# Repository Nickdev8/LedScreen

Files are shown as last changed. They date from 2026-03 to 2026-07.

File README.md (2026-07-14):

<p>
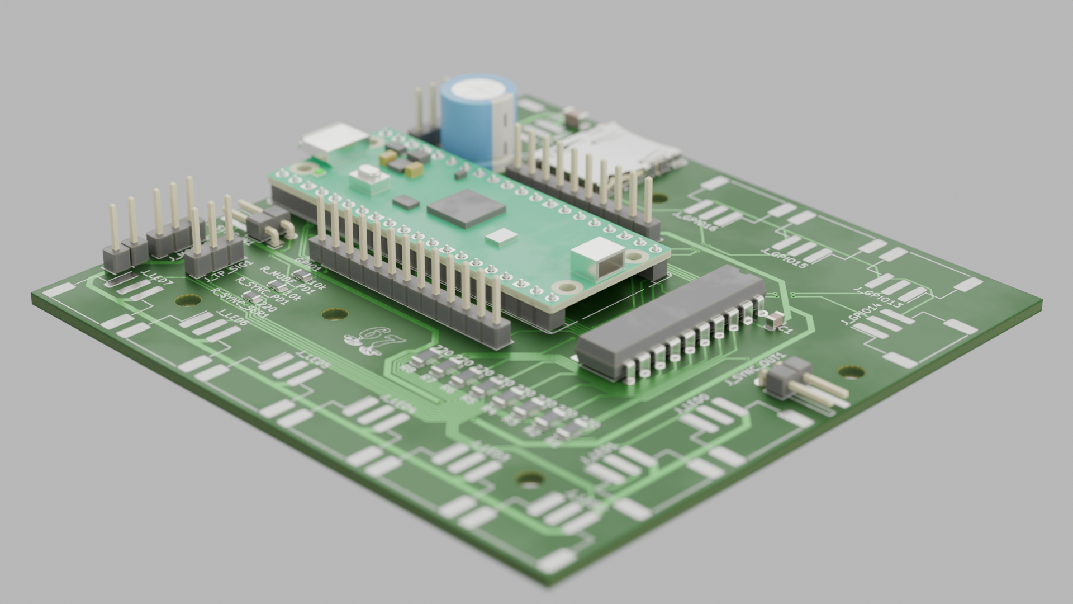
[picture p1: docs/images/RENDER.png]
  
  jlcpcb orders
</p>
# Led Control Board
Status: PCB, Firmware, Hardware and examples are Completly done!

With this board you can control multiple WS2812 LED lines with XLight sequences.
The main idea is that I wanted one board that could handle the panel data, SD card playback, and animation syncing between boards. That i all achieved with this pcb.

## Project Purpose
### Why I Built This
One of my close friends, Ruben, wanted to build a big LED panel project with me so we could display text, animations, and more.
After this board is fully working, I also want to use it in 2 daft punk helmets for Comic-Con 2026.

### BOM
- Raspberry Pi Pico
- 74HCT245
- 1000uF Cap
- 8x 220 ohm Resistor
- 100nF Cap (optionaly)
- 4.7uF Cap (optionaly)
- 2x 10k Res (optionaly for board Sync)

## How do you use it?
If you want to update the code on the MCU, I would really suggest reading [The firmware instuctions](docs/FIRMWARE_INSTUCTIONS.md).
If you want to update the animations on the display, read [the animation instuctions](docs/ANIMATIONS_INSTUCTIONS.md).

The basic idea is:
1. Flash the Pico with the firmware from `arduino_firmware/Main/`.
2. Put `.lsa` animation files in the SD card root.
3. Connect the LED panels and power them from an external regulated 5V PSU.
4. If needed, chain multiple boards together with the sync in/out headers.

## Firmware / Software
The Pico runs my own firmware in the [`arduino_firmware/`](arduino_firmware/) folder.
To Install make sure you have the `Earle Philhower Arduino-Pico core board` library

### SD Card Playback
- The Pico firmware reads root-level `.lsa` files from a FAT32 SD card.
- Files named `startup*.lsa` play once at boot in case-insensitive alphabetical order.
- Every other `.lsa` file then plays in case-insensitive alphabetical order, repeating the complete playlist forever.
- Prefix normal files with numbers such as `01_intro.lsa` and `02_logo.lsa` to control their order.
- Long filenames such as `startup_1.lsa` are supported.
- USB live streaming and GIF playback are not part of the active firmware.

## Project Files
- [`pcb/src/`](pcb/src/LedScreen.kicad_sch) - PCB sourse
- [`pcb/exports/LedScreen.pdf`](pcb/exports/LedScreen.pdf) - exported schematic PDF
- [`pcb/exports/gerber.zip`](pcb/exports/gerber.zip) - gerbers bundled for fabrication upload
- [`pcb/Gerber/`](pcb/Gerber/) - individual gerber outputs
- [`pcb/bom/ibom.html`](pcb/bom/ibom.html) - interactive BOM
- [`mechanical/case/`](mechanical/case/) - case and standoff print files
- [`xlights_project/`](xlights_project/) - xLights example project for driving the board
- [`scripts/fseq_to_lsa.py`](scripts/fseq_to_lsa.py) - convert xLights FSEQ files to `.lsa`

## Notes
I also included an xLights example for controlling this board.
xLights configuration depends on the final data path used between xLights and the Pico.

Start with a smaller amount of daisy-chained panels per output lane while validating signal integrity and power behavior.
Use an external 5V PSU sized for the actual panel count and brightness.

## Bill of Materials
Interactive BOM: [cdn.nickesselman.nl](https://cdn.nickesselman.nl/ledpanel/ibom.html)

## Project Images
<p>
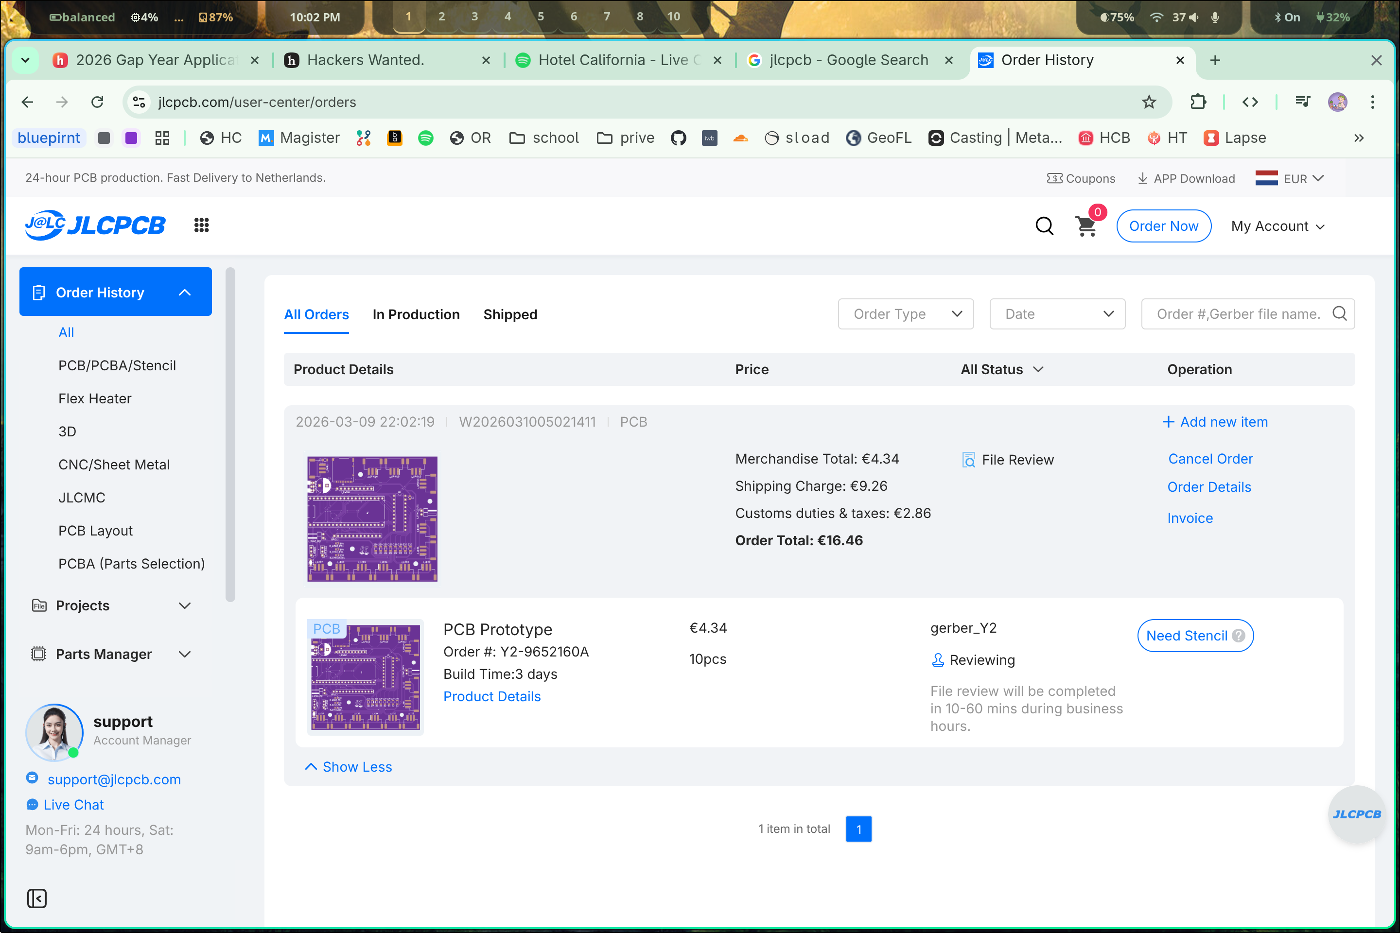
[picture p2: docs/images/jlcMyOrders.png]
jlcpcb orders
  
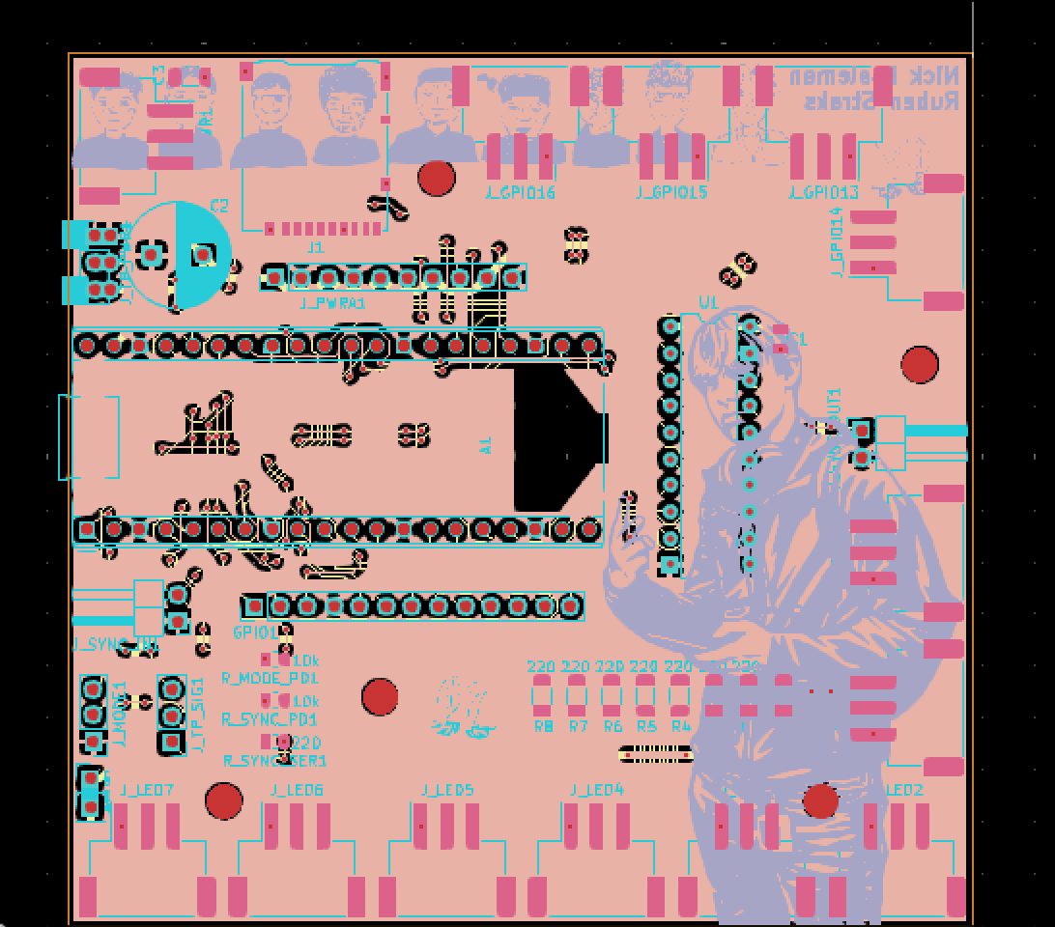
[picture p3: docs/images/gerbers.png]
gerbers
  
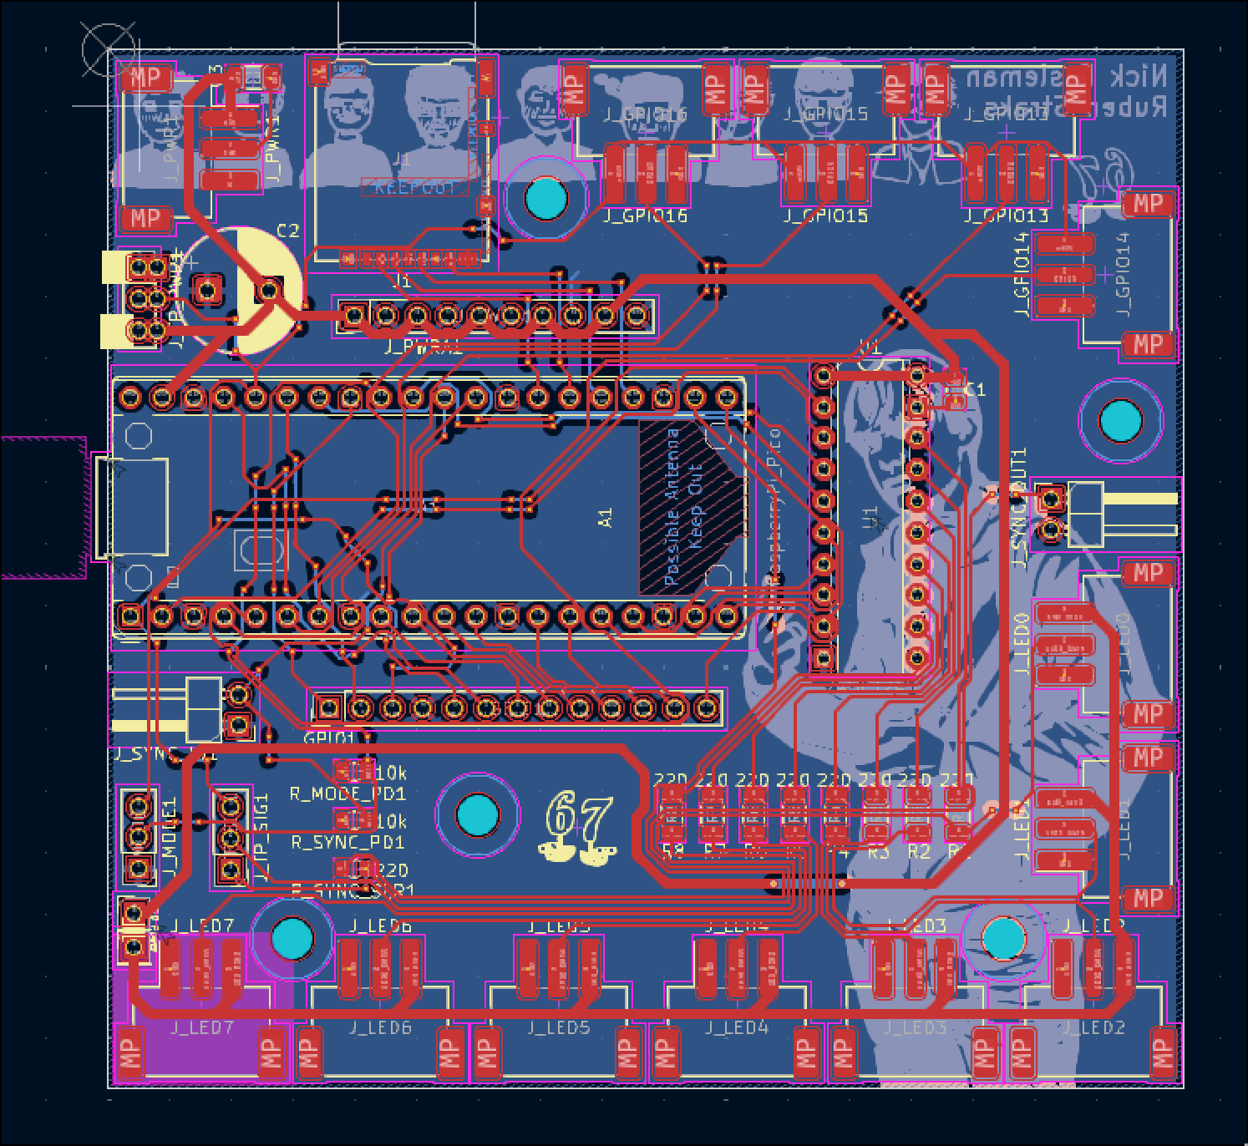
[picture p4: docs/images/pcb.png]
pcb
  
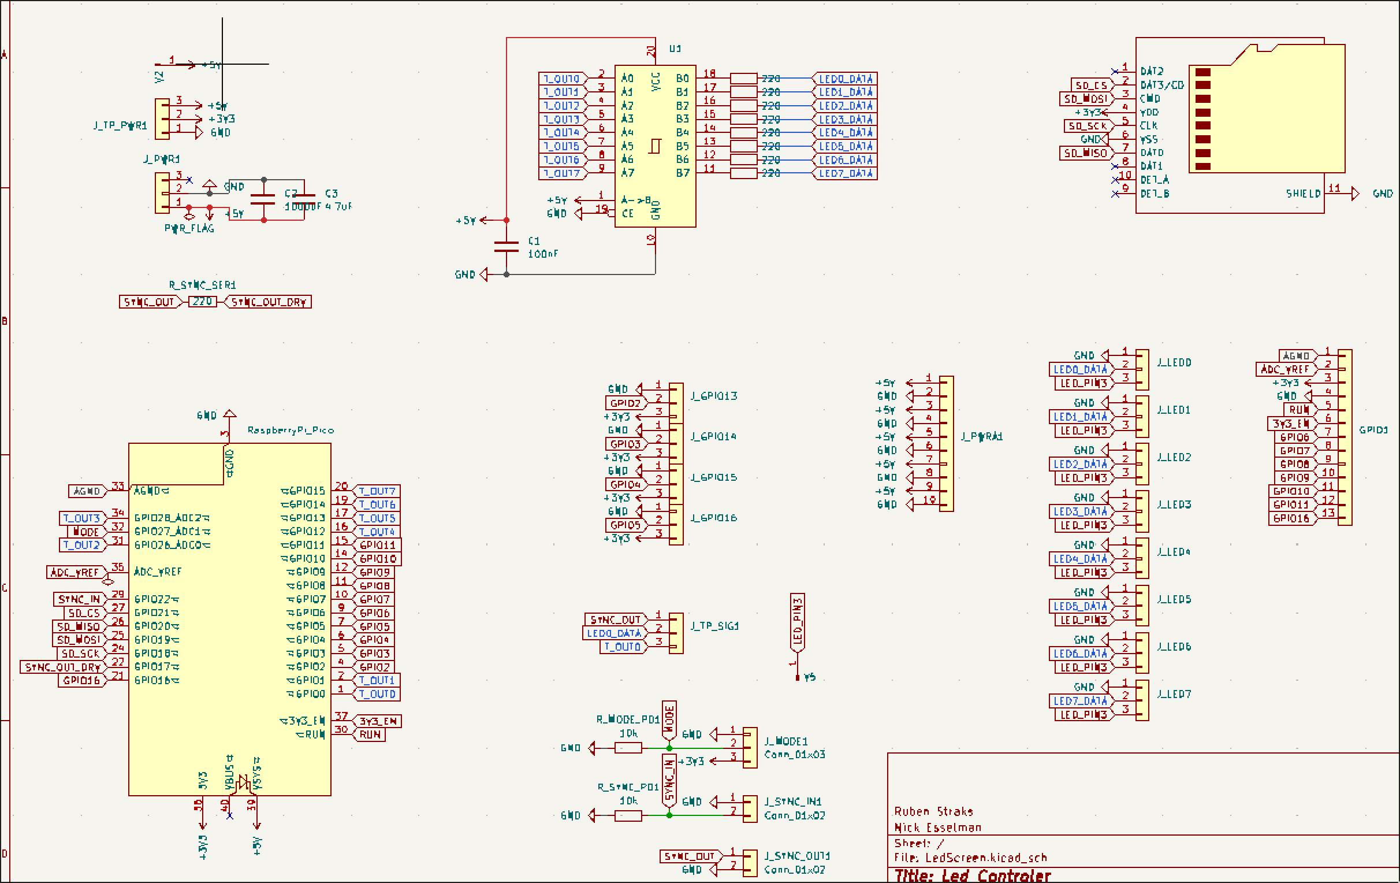
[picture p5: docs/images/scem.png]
schematic
  
</p>

## Build Photos
LED panels on the bench
Controller close-up

## License
- Hardware: CERN-OHL-S
- Firmware/Software: MIT License
- 
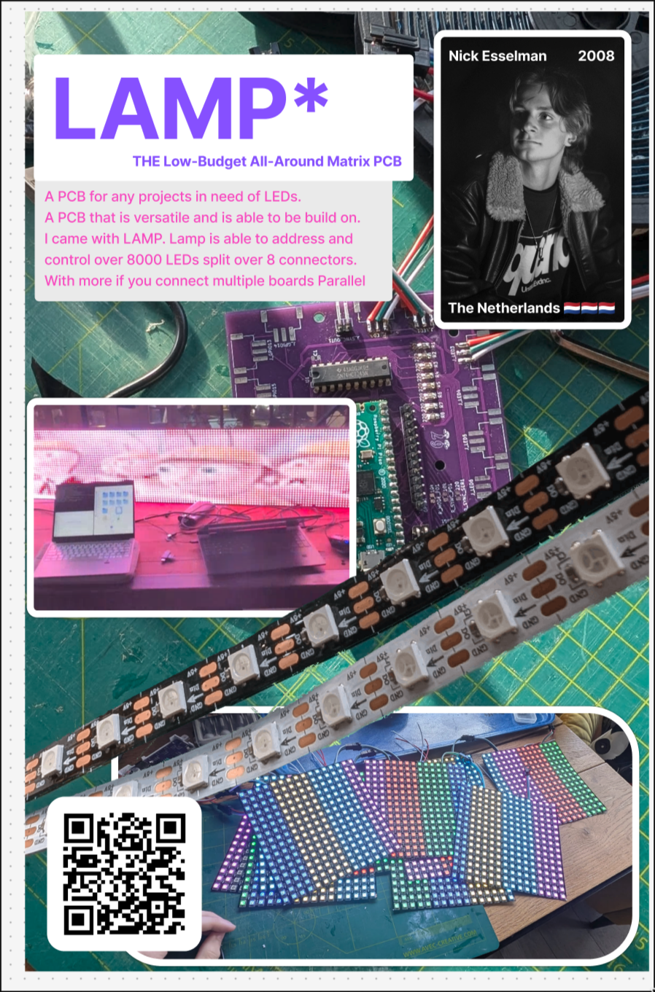
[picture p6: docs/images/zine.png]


# Daft Punk Helmets
I used this project for 2 Helmets, Guy manual (gold) & Thomas (Silver)
all 3d printed in about 200h of print time. and LED strips on the inside for the classic robot screen.
Models are in the repo and how i made this you can google and find on instrucables

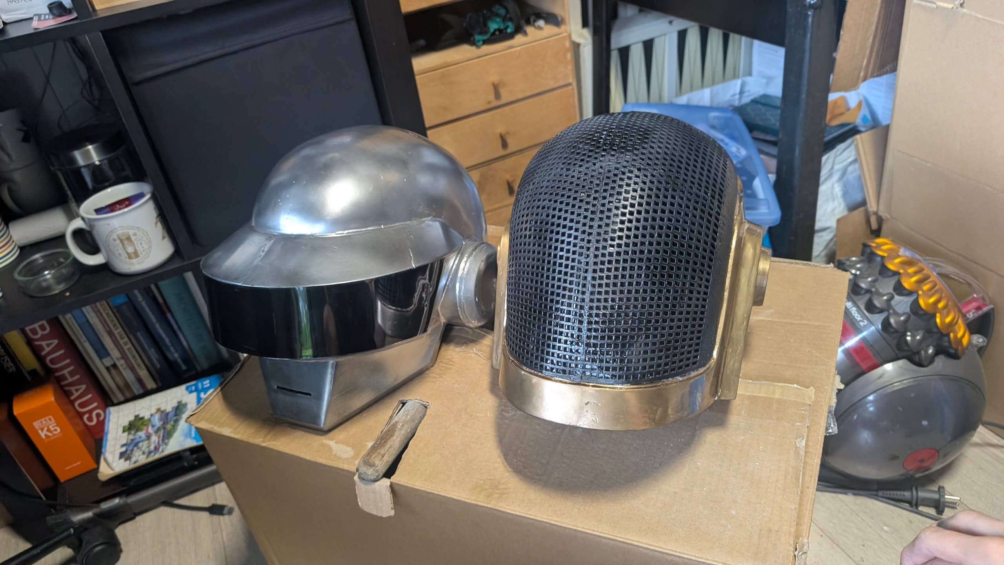
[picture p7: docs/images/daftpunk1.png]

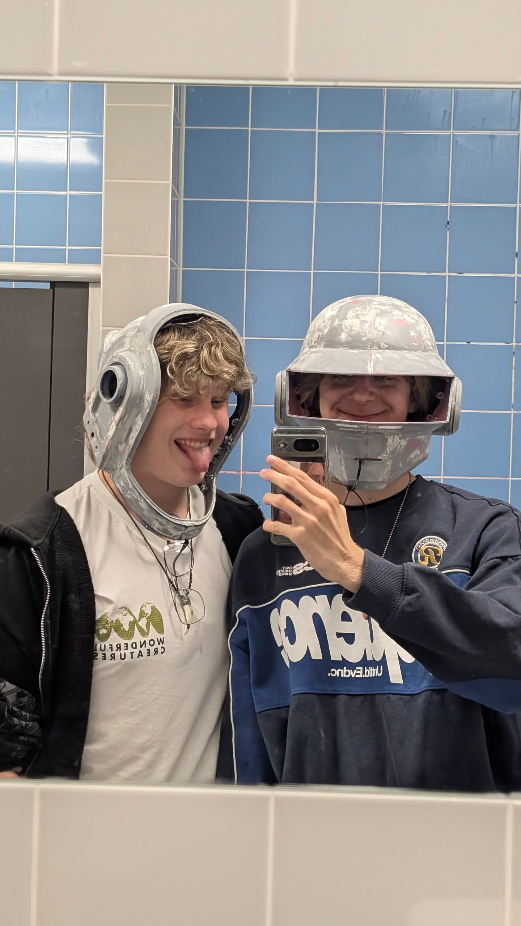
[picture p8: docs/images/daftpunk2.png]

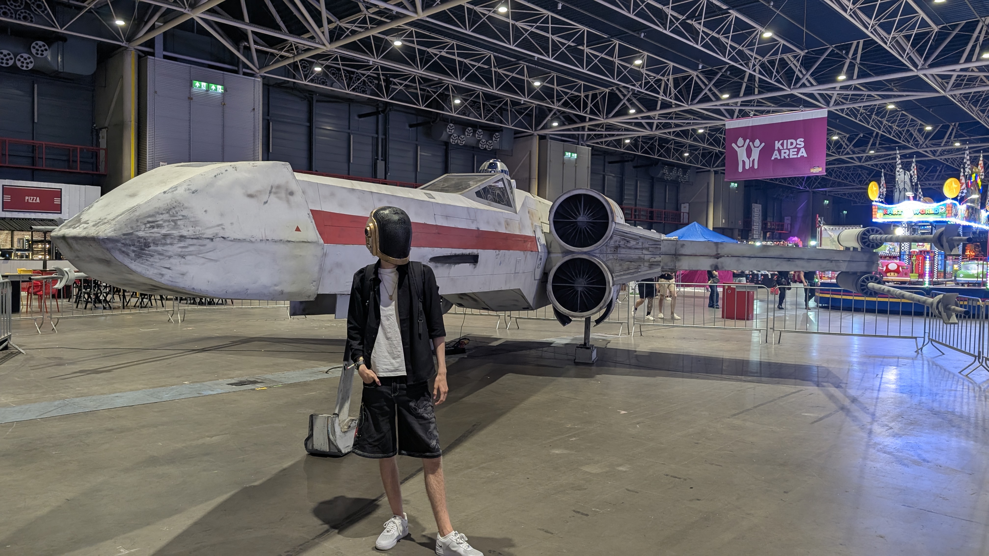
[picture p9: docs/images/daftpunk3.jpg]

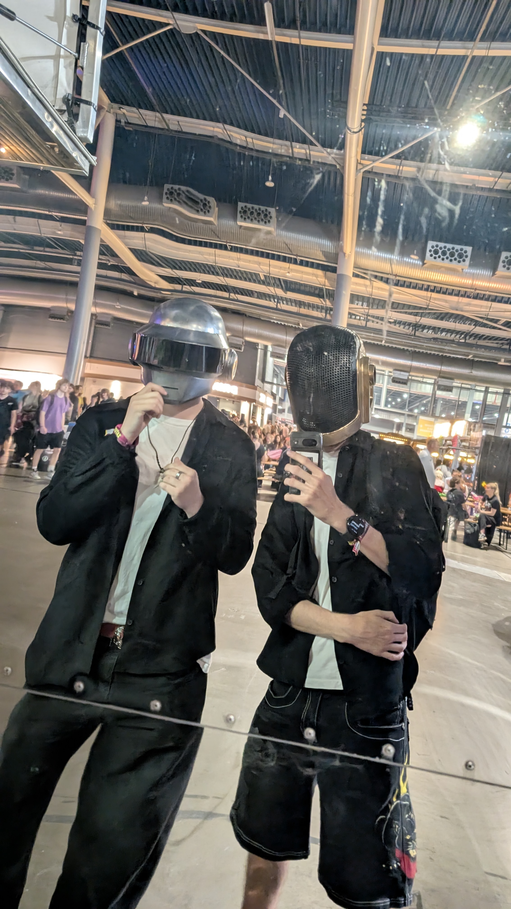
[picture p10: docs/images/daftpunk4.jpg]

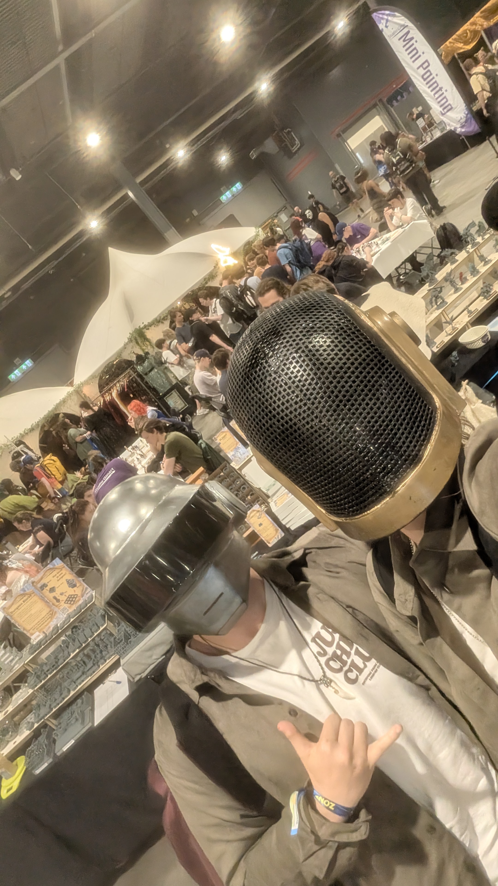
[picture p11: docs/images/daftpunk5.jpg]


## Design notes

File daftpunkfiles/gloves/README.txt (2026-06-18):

Daft Punk Gloves by KingHelps on Thingiverse: https://www.thingiverse.com/thing:177614

Summary:
Print yourself some Daft Punk gloves to go with the helmet!

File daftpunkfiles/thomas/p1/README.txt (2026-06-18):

Daft Punk Thomas 3D Printable Wearable Helmet by bendiger on Thingiverse: https://www.thingiverse.com/thing:338831

Summary:
If you like this design, buy me a beer :)http://www.thingiverse.com/bendiger/aboutUPDATE 09-17-16Thanks to all the hard work of Nathan720 (http://www.thingiverse.com/Nathan720), there is now an instructables post for how to build the helmets!http://www.instructables.com/id/Two-Daft-Punk-Helmets-in-One-Month/All the parts will be for the left side and just need to be mirrored to print the right.This design is for small 3D Printers with print beds 6x6in or bigger.All parts Zip tie or glue together.Support Material is a must unless you have a lot of faith in your printers capabilities and you can print extreme overhangs.About 120 hours of printing so far, and 2 reels of 3mm abs.It will be compatible with the AlexPlusLEDs matrix and side bar kits found here: http://alexplusleds.bigcartel.com/STL files orientated for printing on a 6x6 bed.Want the Guy Manuel Helmet? Here it is:http://www.thingiverse.com/thing:470882UPDATE 05-22-14: I've added the Visor to the list of files. Support material is required, I haven't made these with supports built-in yet, version 2 maybe.. More to follow soon.UPDATE 05-26-14: I've added the dome parts. I'm still working on the electronics mounts, those might be a while..UPDATE 09-01-14 I added the visor to the list of parts. This can be used to make molds from or bend plexiglass around and then cut to fit.UPDATE: 09-20-14Electronic mounts are finally done.Helmet design for V1 is done.Please tell me what changes you would like made. I want this to be the best version it can be.UPDATE: 10-10-14I've uploaded larger versions of all the parts after some feedback about the Guy Man helmet seeming larger. Turns out the Thomas was too small. The electronic mounts will be done soon. Little more work needed. The parts with v1.5 are the scaled versions. I've left the original parts.UPDATE 10-26-15Thought I should clarify some things since there seems to be some confusion. All of the parts that list v1.5 are a slightly larger version. the rest of the parts, 1.3, 1, and some without versioning, are the smaller helmet. There is an instructables that Fictive made recently on how to put the helmet together. http://goo.gl/cWfsDO

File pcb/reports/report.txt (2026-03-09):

Warning: Width correction constrained.  The width correction value must be in the range of [0,000001 mm; 0,199999 mm] for the current design rules.
Plotted to '/home/nick/Documents/projects/LedScreen/src/LedScreen-F_Cu.gtl'.
Plotted to '/home/nick/Documents/projects/LedScreen/src/LedScreen-B_Cu.gbl'.
Plotted to '/home/nick/Documents/projects/LedScreen/src/LedScreen-F_Silkscreen.gto'.
Plotted to '/home/nick/Documents/projects/LedScreen/src/LedScreen-B_Silkscreen.gbo'.
Plotted to '/home/nick/Documents/projects/LedScreen/src/LedScreen-F_Mask.gts'.
Plotted to '/home/nick/Documents/projects/LedScreen/src/LedScreen-B_Mask.gbs'.
Plotted to '/home/nick/Documents/projects/LedScreen/src/LedScreen-Edge_Cuts.gm1'.
Created Gerber job file '/home/nick/Documents/projects/LedScreen/src/LedScreen-job.gbrjob'.
Info: Done.
Plotted to '/home/nick/Documents/projects/LedScreen/src/geibers/LedScreen-F_Cu.gtl'.
Plotted to '/home/nick/Documents/projects/LedScreen/src/geibers/LedScreen-B_Cu.gbl'.
Plotted to '/home/nick/Documents/projects/LedScreen/src/geibers/LedScreen-F_Silkscreen.gto'.
Plotted to '/home/nick/Documents/projects/LedScreen/src/geibers/LedScreen-B_Silkscreen.gbo'.
Plotted to '/home/nick/Documents/projects/LedScreen/src/geibers/LedScreen-F_Mask.gts'.
Plotted to '/home/nick/Documents/projects/LedScreen/src/geibers/LedScreen-B_Mask.gbs'.
Plotted to '/home/nick/Documents/projects/LedScreen/src/geibers/LedScreen-Edge_Cuts.gm1'.
Created Gerber job file '/home/nick/Documents/projects/LedScreen/src/geibers/LedScreen-job.gbrjob'.
Info: Done.
Info: Done.
Info: Done.

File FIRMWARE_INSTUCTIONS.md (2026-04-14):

Things to note:
Ill first explain updating the firmware via the sd card. then via BOOTSEL. then via the andriod ide.

Putting new code on the board is not requered to update the LED animations.

To update LED aniamtions Please read [The animation Instuctions](ANIMATIONS_INSTUCTIONS.md)

The sd card reads for a file named [firmware.uf2](example_firmware.uf2). You can build this file from the adruino ide or find the latest in the [Repo's Releases page](https://github.com/Nickdev8/LedScreen/releases)

The other way is to hold down the BOOTSEL button while pluggin the usb of the pico into a laptop. and you should see a new drive apear. put the .uf2 file in there and next time you plug it in without holding the BOOTSEL button. it should load the new code.

The last option is to plug the Pico in with BOOTSEL pressed and uploading the sketch directly from the Adruino IDE. you would need to have the right libraries and board installed for this. linked here:

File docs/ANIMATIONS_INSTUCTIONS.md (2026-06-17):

# Animation files

Copy `.lsa` animation files into the root of a FAT32-formatted SD card.

On each boot:

1. Every file named `startup*.lsa` plays once in case-insensitive alphabetical order.
2. All other `.lsa` files play in case-insensitive alphabetical order.
3. After the final normal animation, the normal playlist starts again.

Examples:

- `startup.lsa`
- `startup_1.lsa`
- `01_intro.lsa`
- `02_logo.lsa`

Startup files are not included in the repeating playlist. If there are no startup files, normal playback begins immediately. If there are no normal files, the panel returns to its idle error indication after the startup files finish.

Generate `.lsa` files from xLights FSEQ exports with [`scripts/fseq_to_lsa.py`](../scripts/fseq_to_lsa.py), or convert videos with [`scripts/mp4_to_lsa.py`](../scripts/mp4_to_lsa.py). The xLights project is in [`xlights_project/`](../xlights_project/).

The active firmware reads animations only from the SD card. USB live preview and GIF playback are not supported.

To change the board size, update [`arduino_firmware/Main/Config.h`](../arduino_firmware/Main/Config.h) and rebuild the firmware.

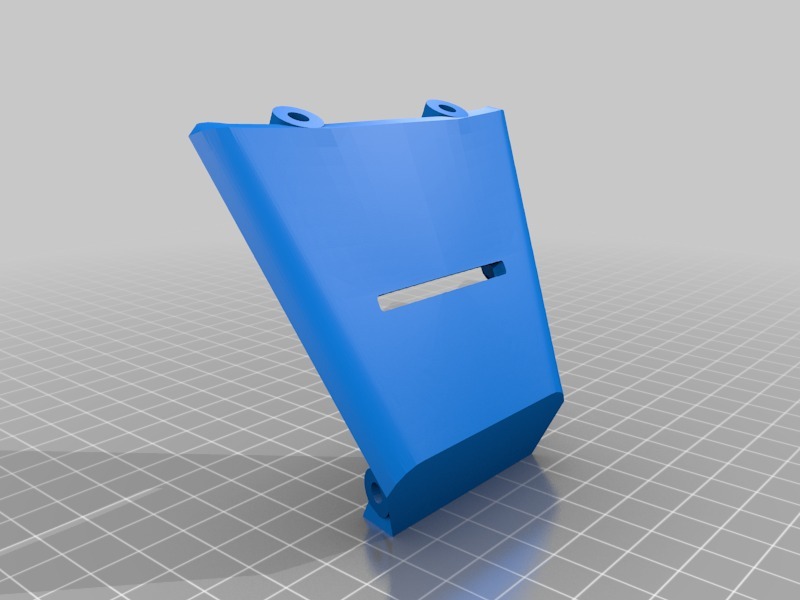
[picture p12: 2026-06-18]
daftpunkfiles/thomas/p1/images/Thomas_Helmet-Mouth.jpg

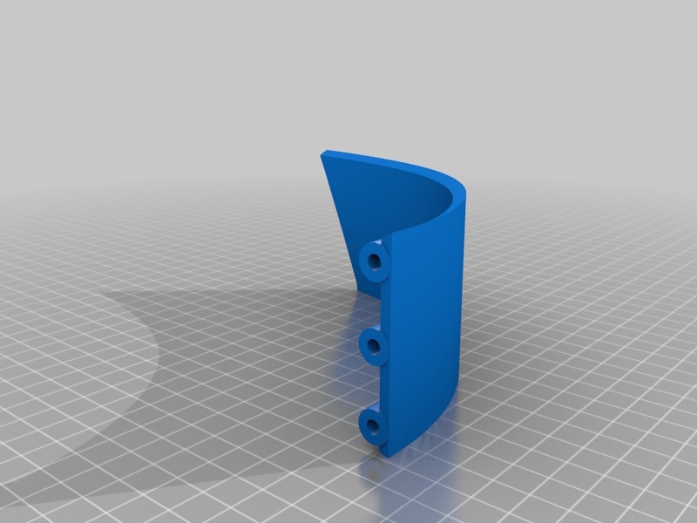
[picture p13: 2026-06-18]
daftpunkfiles/thomas/p1/images/Thomas_Helmet-VisorL.jpg

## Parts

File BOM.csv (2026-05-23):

Minimal Requred | Component name | Unit Price | pcb qty | Order qty | PART / LCSC | Distributor | Link / Notes | Total Price
TRUE | Raspberry Pi Pico | €3.5900 | 1 | 1 | RP2040 Pico | AliExpress | https://nl.aliexpress.com/item/1005009890247801.html?mp=1 | €3.59
TRUE | Micro SD card socket | €0.1590 | 1 | 10 | TF push-push 9pin | AliExpress | https://nl.aliexpress.com/item/1005001331379046.html?mp=1 | €1.59
FALSE | JST-SM 3-PIN Header Female | €0.0164 | 20 | 50 | PSB Connector | AliExpress | https://nl.aliexpress.com/item/1005009483624961.html?mp=1 | €0.82
FALSE | JST-SM 3-PIN Header Male | €0.0299 | 20 | 100 | PSB Connector | AliExpress | https://nl.aliexpress.com/item/1005005362711029.html?mp=1 | €2.99
FALSE | JST-XH LED connector cabel | €0.1750 | 20 | 40 | PSB Connector | AliExpress | https://nl.aliexpress.com/item/1005009696690444.html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 | €7.00
TRUE | SN74HCT245N | €0.7202 | 1 | 5 | C133640 | LCSC | https://www.lcsc.com/product-detail/C133640.html | €3.60
TRUE | 220Ω resistor 0805 | €0.0021 | 8 | 300 | C17557 | LCSC | https://www.lcsc.com/product-detail/C17557.html | €0.63
FALSE | 10kΩ resistor 0805 | €0.0020 | 2 | 200 | C84376 | LCSC | https://www.lcsc.com/product-detail/C84376.html | €0.40
FALSE | 100nF Capacitor 0805 | €0.0045 | 2 | 200 | C49678 | LCSC | https://www.lcsc.com/product-detail/C49678.html | €0.90
FALSE | 4.7uF Capacitor 1206 | €0.0339 | 1 | 50 | C51205 | LCSC | https://www.lcsc.com/product-detail/C51205.html | €1.70
TRUE | 1000uF Capacitor | €0.0843 | 1 | 10 | C51205 | LCSC | https://www.lcsc.com/product-detail/C72470.html | €0.84
FALSE | Pin header for Pico and Sync pins | €0.1273 | 5 | 15 | 2×20 pin header | LCSC | https://www.lcsc.com/product-detail/C2337.html | €1.91
FALSE |  |  |  |  |  |  |  | €0.00
FALSE | WS2812B 16×16 LED panel | €4.0900 | 25 | 25 | WS2812B 16×16 LED panel | Alibaba | https://dutch.alibaba.com/product-detail/WS2812B-RGB-Flexible-16x16-8x32-256Leds-1601298120275.html | €102.25
FALSE | WS2812B 5050 RGBIC LED-strip | €5.3900 | 3 | 3 | 5M 60 IP30 | AliExpress | https://nl.aliexpress.com/item/1005009321343937.html?mp=1 | €16.17
TRUE | 5V 30A PSU | €19.9900 | 2 | 2 | 5V 30A PSU | Amazon | https://www.amazon.nl/-/en/Adapter-Universal-Transformer-Computer-Surveillance/dp/B07PRY73TN | €39.98
FALSE |  |  |  |  |  | AliExpress |  | €0.00
FALSE | 16AWG power wire | €8.9900 | 5–10m | 1 | Routing to Panels | AliExpress | https://nl.aliexpress.com/item/1005008563402600.html?curPageLogUid=UtoHJnuT4ywC | €8.99

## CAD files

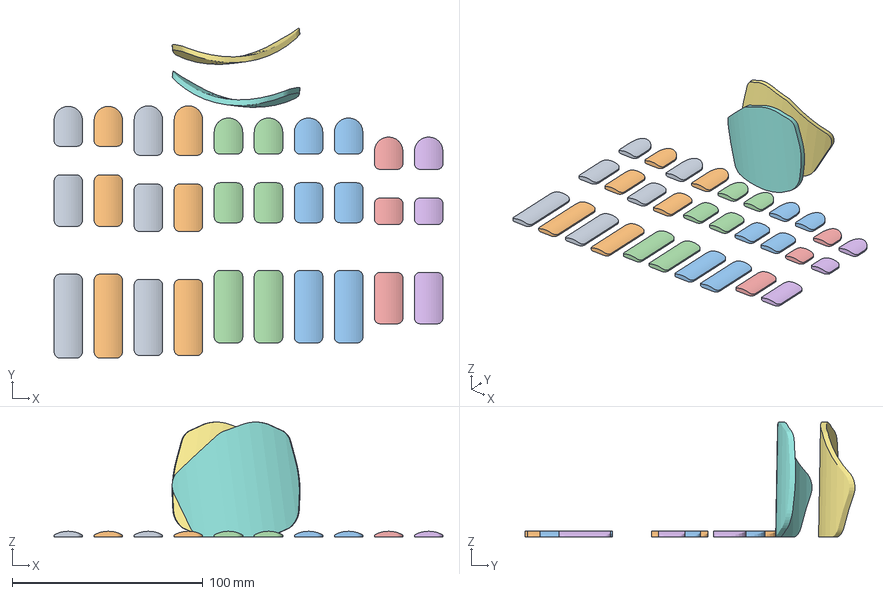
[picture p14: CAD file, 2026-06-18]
daftpunkfiles/gloves/complete1pair.3mf
204.0 x 173.1 x 60.2 mm
Thumb.stl
Ring.stl
Pinky.stl
Palm_mirrored.stl
Palm.stl
Middle.stl
Index.stl

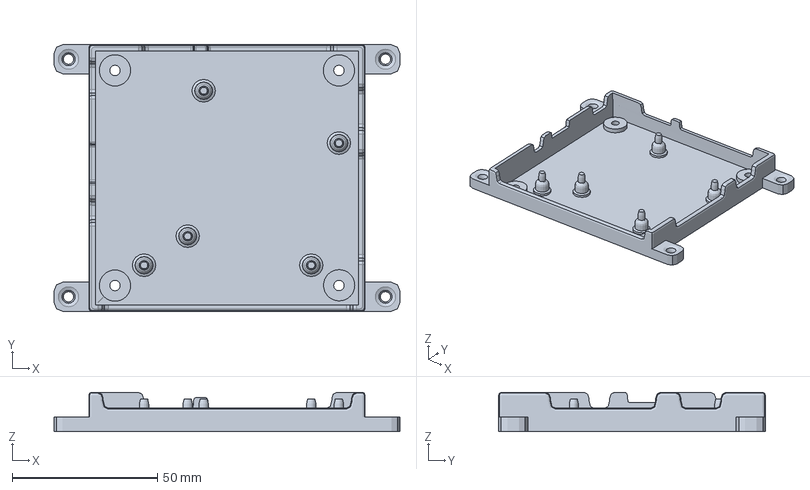
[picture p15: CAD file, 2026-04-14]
mechanical/case/casefull.3mf
119.0 x 91.7 x 13.5 mm

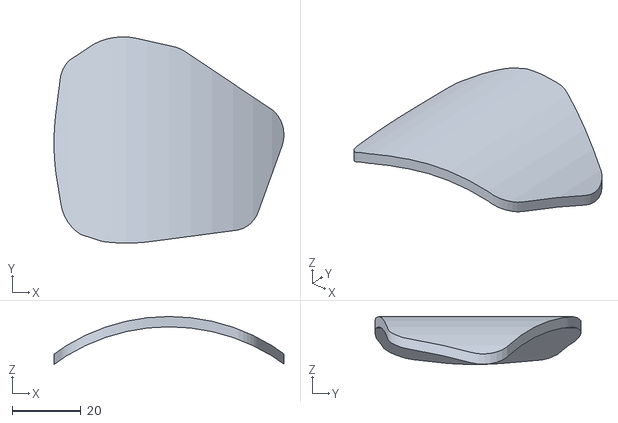
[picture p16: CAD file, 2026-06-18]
daftpunkfiles/gloves/files/Palm_mirrored.stl
66.9 x 60.0 x 14.0

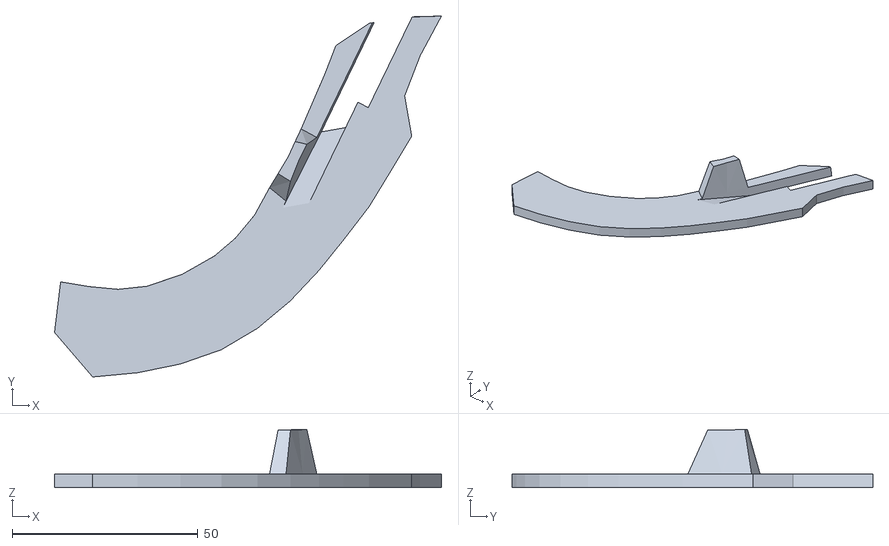
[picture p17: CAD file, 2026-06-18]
daftpunkfiles/guy manual/files/ChinLightMount-v1.5.stl
104.1 x 97.1 x 15.7

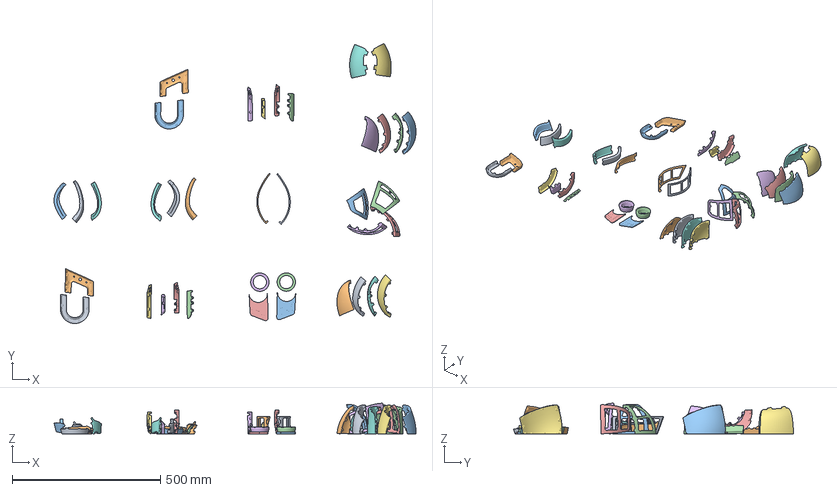
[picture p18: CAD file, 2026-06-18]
daftpunkfiles/guy manual/plates/leftside.3mf
1221.8 x 945.0 x 103.6 mm
SideTop-v1.5.stl
SideBottom-v1.5.stl
BackBar-v1.5.stl
SideShroud-BF-v1.5.stl
SideShroud-TB-v1.5.stl
SideShroud-BB-v1.5.stl
SideShroud-TF-v1.5.stl
TopBar-v1.5.stl
Chin-v1.5.stl
M-SideBottom-v1.5.stl
M-SideTop-v1.5.stl
M-SideShroud-BF-v1.5.stl
M-SideShroud-TB-v1.5.stl
M-SideShroud-TF-v1.5.stl
M-SideShroud-BB-v1.5.stl
M-TopBar-v1.5.stl
M-BackBar-v1.5.stl
M-Chin-v1.5.stl
VisorBottom-v1.5.stl x 2
VisorMidBottom-v1.5.stl x 2
VisorMidTop-v1.5.stl x 2
VisorTop-v1.5.stl x 2
visor1.stl
visor2.stl
visor3.stl
visor4.stl
BackWireHarness-V1.5.stl
M-BackWireHarness-V1.5.stl
thomasvisorl.stl
M-thomasvisorl.stl
CircuitPannel-v1.5.stl x 2
EarCupLR-Electronics-V1.5.stl x 2

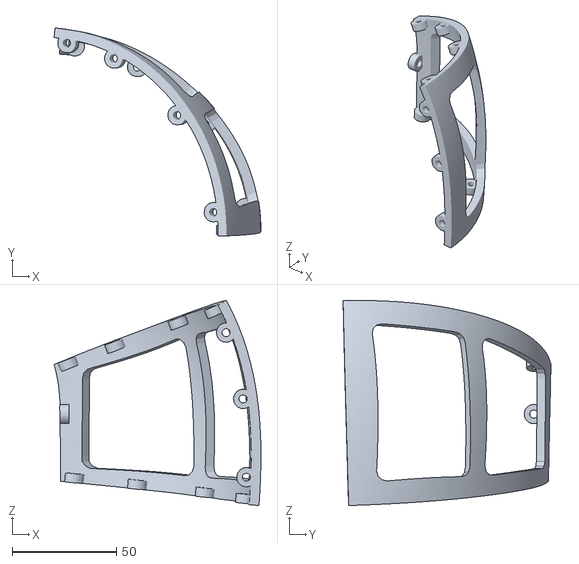
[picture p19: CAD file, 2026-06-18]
daftpunkfiles/guy manual/visor3.stl
99.2 x 99.6 x 98.3

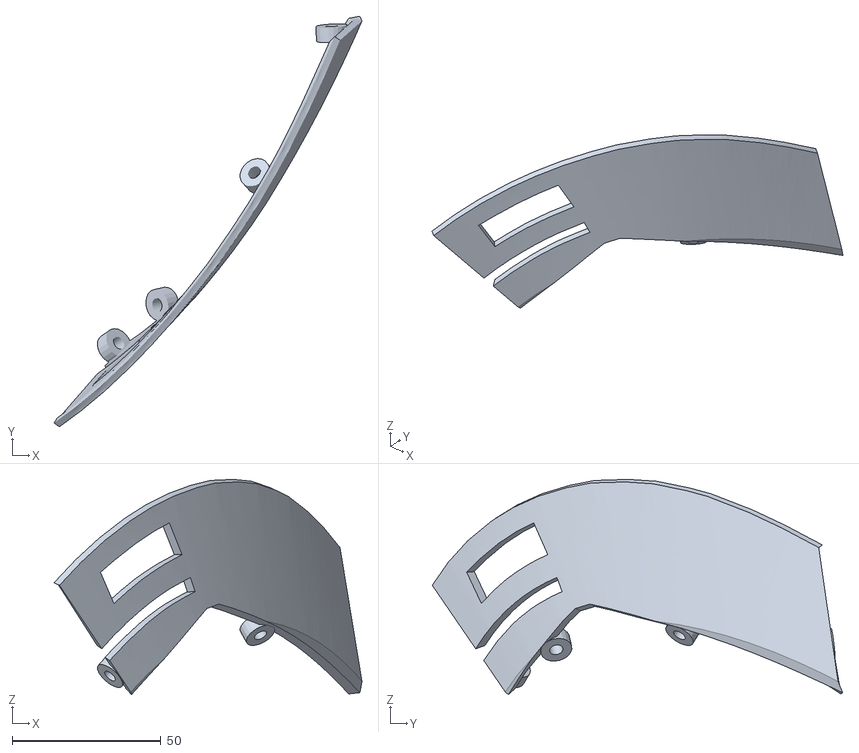
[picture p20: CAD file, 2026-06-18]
daftpunkfiles/thomas/p1/files/Thomas_Helmet-BottomVisor-Front-V1.5.stl
103.7 x 138.2 x 72.4

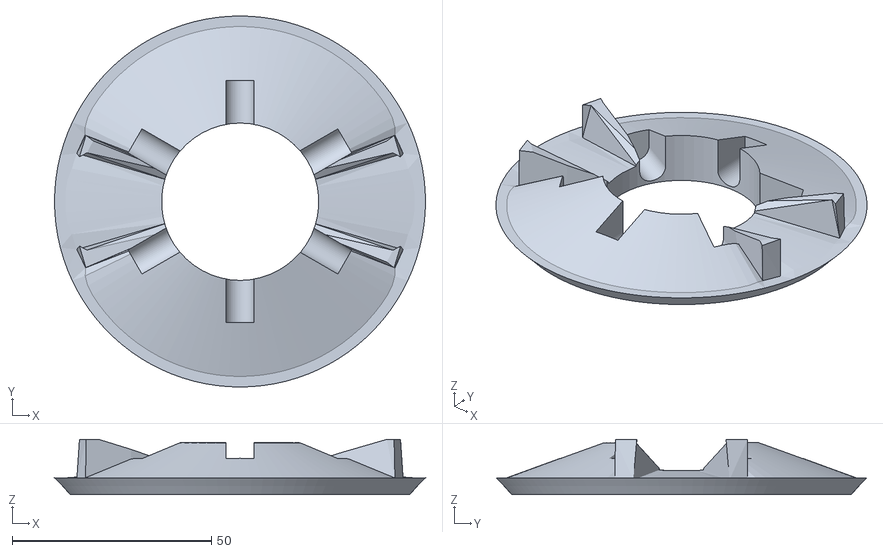
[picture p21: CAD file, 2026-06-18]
daftpunkfiles/thomas/p2/files/LightRing-v1.5.stl
93.2 x 93.2 x 13.9

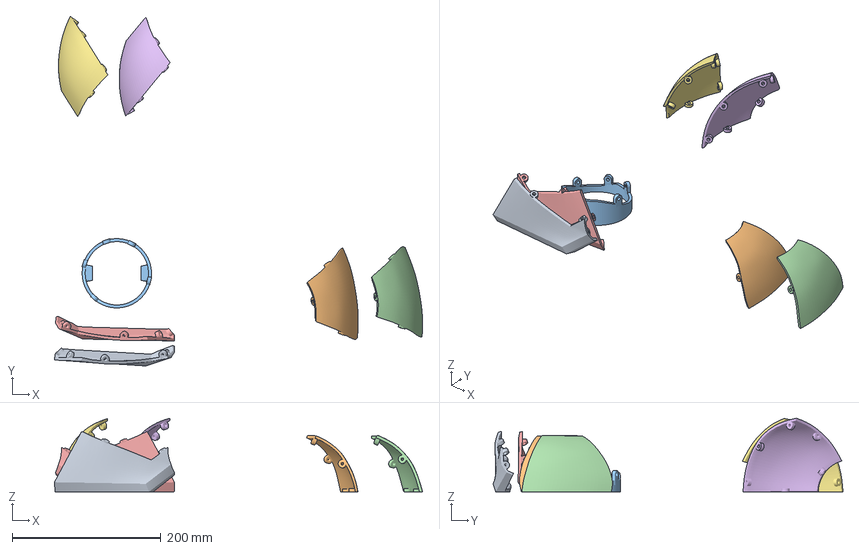
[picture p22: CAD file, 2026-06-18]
daftpunkfiles/thomas/thomastuhis.3mf
495.1 x 470.7 x 99.0 mm
Thomas_Helmet-Cheek-V1.5.stl
Thomas_Helmet-Dome-Side-V1.5.stl
M-Thomas_Helmet-EarMount-v1.5.stl
M-Thomas_Helmet-Dome-Side-V1.5.stl
M-Thomas_Helmet-Cheek-V1.5.stl
M-Thomas_Helmet-Dome-Back-Top-V1.5.stl
Thomas_Helmet-Dome-Back-Top-V1.5.stl

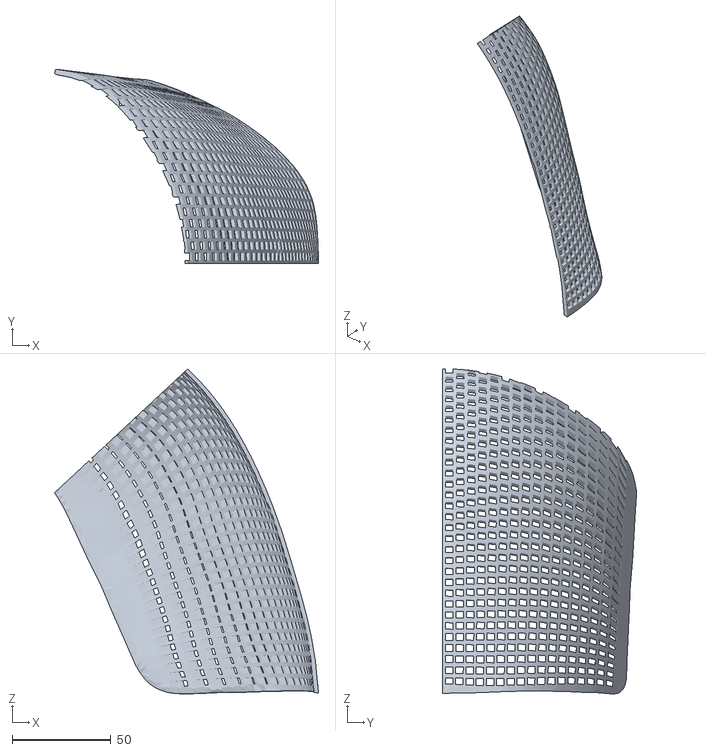
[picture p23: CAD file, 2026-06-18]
daftpunkfiles/visor2.stl
133.8 x 98.4 x 164.7

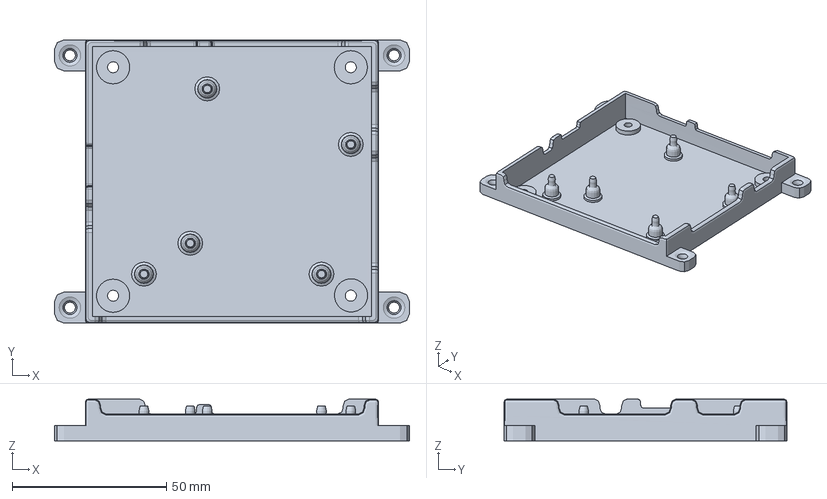
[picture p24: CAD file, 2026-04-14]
mechanical/case/StandOff.3mf
115.0 x 91.7 x 13.5 mm

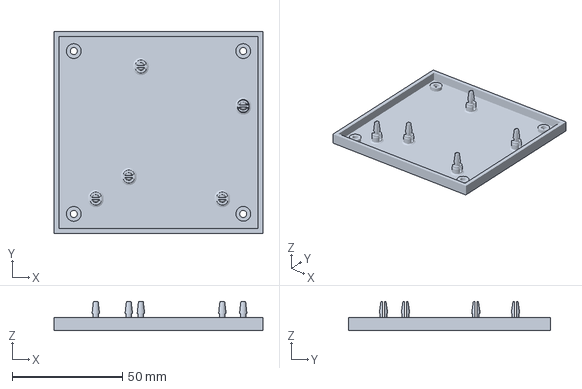
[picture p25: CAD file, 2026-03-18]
StandOff.3mf
95.0 x 91.7 x 13.2 mm

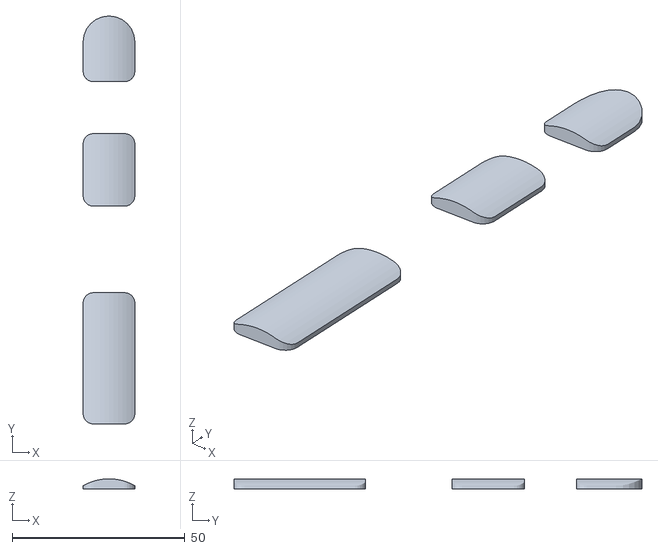
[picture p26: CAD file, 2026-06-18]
daftpunkfiles/gloves/files/Ring.stl
15.0 x 118.0 x 3.00

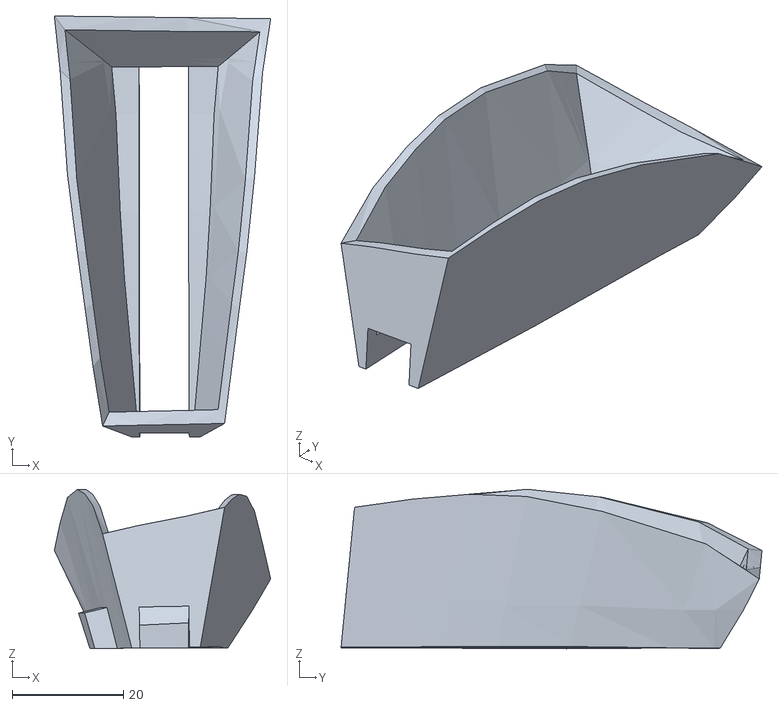
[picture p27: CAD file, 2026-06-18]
daftpunkfiles/guy manual/files/Fan-1_TopL-v1.5.stl
38.8 x 75.5 x 28.6

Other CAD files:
daftpunkfiles/guy manual/visor4.stl
daftpunkfiles/thomas/p1/files/Thomas_Helmet-Dome-Side.stl
daftpunkfiles/thomas/p2/files/Thomas_Helmet-Mouth-V1.5.stl
daftpunkfiles/thomas/thomas-1side.3mf
StandOff.stl
daftpunkfiles/gloves/files/Index.stl
daftpunkfiles/gloves/files/Middle.stl
daftpunkfiles/gloves/files/Palm.stl
daftpunkfiles/gloves/files/Pinky.stl
daftpunkfiles/gloves/files/Thumb.stl
daftpunkfiles/guy manual/files/BackBar-v1.5.stl
daftpunkfiles/guy manual/files/BackWireHarness-V1.5.stl
daftpunkfiles/guy manual/files/Chin-v1.5.stl
daftpunkfiles/guy manual/files/CircuitPannel-v1.5.stl
daftpunkfiles/guy manual/files/EarCupElectronicsBracket-V1.5.stl
daftpunkfiles/guy manual/files/EarCupLR-Electronics-V1.5.stl
daftpunkfiles/guy manual/files/Fan-2L-v1.5.stl
daftpunkfiles/guy manual/files/Fan-3L-v1.5.stl
daftpunkfiles/guy manual/files/Fan-4L-v1.5.stl
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

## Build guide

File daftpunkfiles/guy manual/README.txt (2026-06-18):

Daft Punk Guy Manuel 3D Printable Wearable Helmet by bendiger on Thingiverse: https://www.thingiverse.com/thing:470882

Summary:
If you like this design, buy me a beer :)http://www.thingiverse.com/bendiger/aboutUPDATE! 03-29-2025I know, sorry.... its been a while... I'm posting these updates for those that have asked. All version 2 files should be printed. All older files are out of date. I may delete them at some point. I've uploaded the 3MF, I can upload the STLs on request, but you will have to figure out the layout.This has been scaled to fit my head and the average head size of most people. Its also designed to fix on a Bambu Lab X1C. The 3MF file has everything laid out and oriented to the bed. I STRONGLY suggest supports. This is way less parts, and I have no plans on changing the assembly method. I have not printed this at all, so use at your own risk. I want to do more, but I already have both helmets. So unless people start donating, this is all I'm doing.UPDATE 09-17-16Thanks to all the hard work of Nathan720 (http://www.thingiverse.com/Nathan720), there is now an instructibles post for how to build the helmets!http://www.instructables.com/id/Two-Daft-Punk-Helmets-in-One-Month/It's what everyone has been waiting for!The Daft Punk Guy Manuel 3D Printable helmet for small printers!All the parts are for the left side and just need to be mirrored to print the right. Set the X scale to -1This design is for small 3D Printers with print beds 6x6in or bigger.All parts Zip tie or glue together.Support Material is a must for most parts. These are not optimized for supportless printing due to there shape.About 60 hours of printing so far, and 1 reels of 3mm abs.It will be compatible with the AlexPlusLEDs fans and chin lights which can be found here: http://alexplusleds.bigcartel.com/STL files are orientated for printing on a 6x6 bed.The visor mold that will soon be included can be used to make your own clear visor form for vacuum forming.Want the Thomas Bangalter Helmet? Here it is:http://www.thingiverse.com/thing:338831---UPDATES---06-27-15 Well, I should have updated this a while back. All the files are updated and scaled to match the Thomas Helmet. Hopefully they look good and work better size wise.10-16-14 I uploaded a quick Back Wire Harness for the wires on the back of the head. Its simple and will be updated to have groves to hold the wires in place.10-04-14 I've uploaded the visor mold and the support parts. All parts should be mirrored and glued together very well to handle vacuum forming. I suggest a good thick coat of epoxy or bondo on the inside of the mold to avoid cracking during forming. Please let me know if there are any problems with slicing, some of the parts were a rush job and didn't need to look pretty.Also, I have uploaded the ear cups and side panels. The ear cup is not ready for electronics, it was uploaded because of a request.

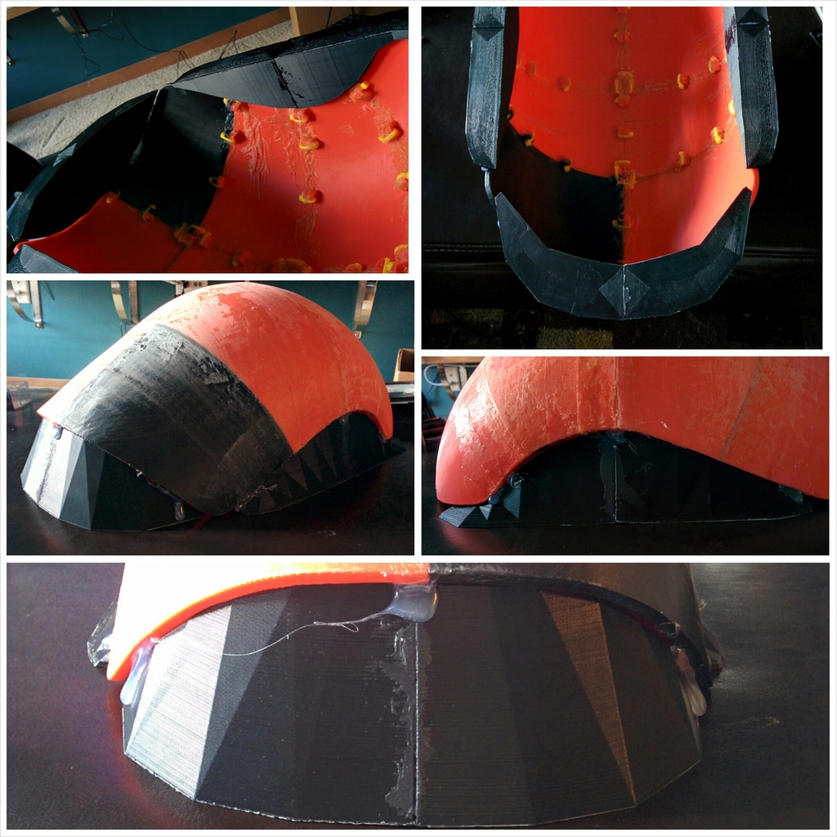
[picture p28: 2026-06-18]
daftpunkfiles/guy manual/images/September_27__2014_at_0333PM.jpg

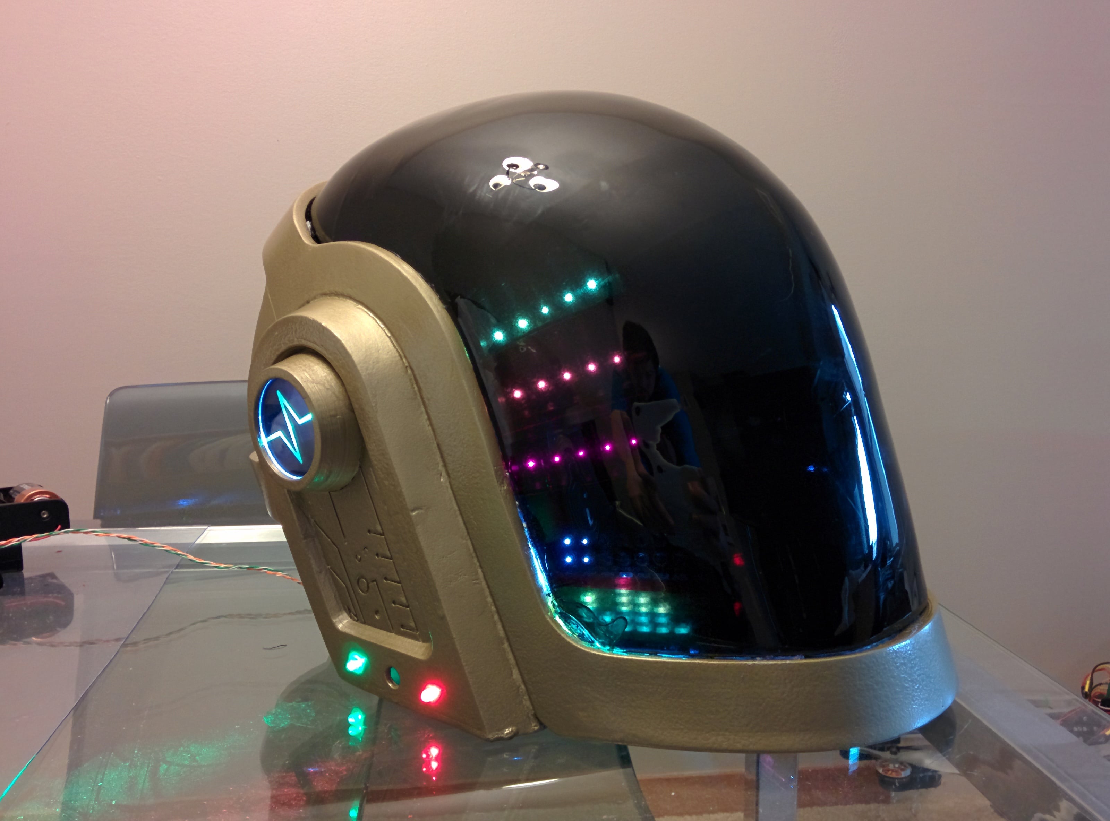
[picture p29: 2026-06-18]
daftpunkfiles/guy manual/images/November_02__2014_at_0413PM.jpeg

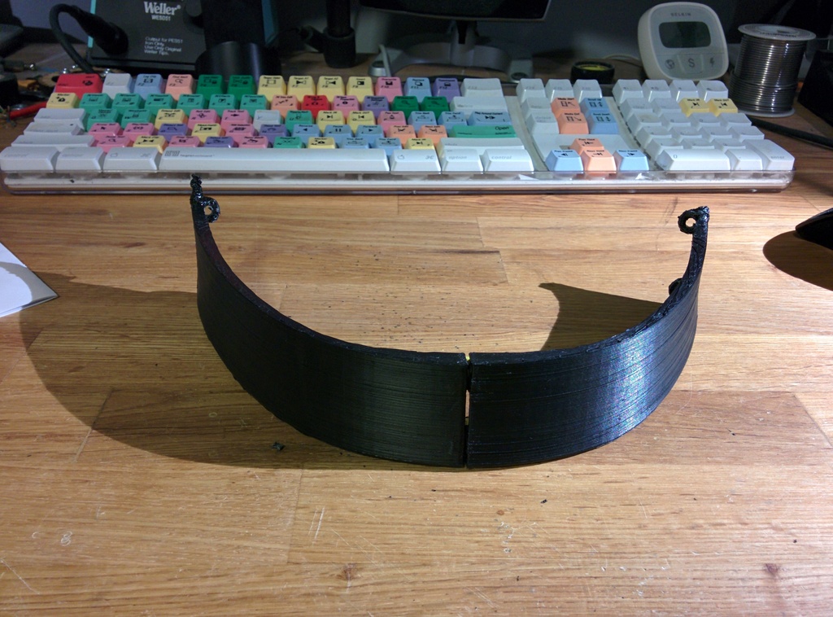
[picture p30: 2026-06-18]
daftpunkfiles/guy manual/images/August_03__2014_at_1111PM.jpg

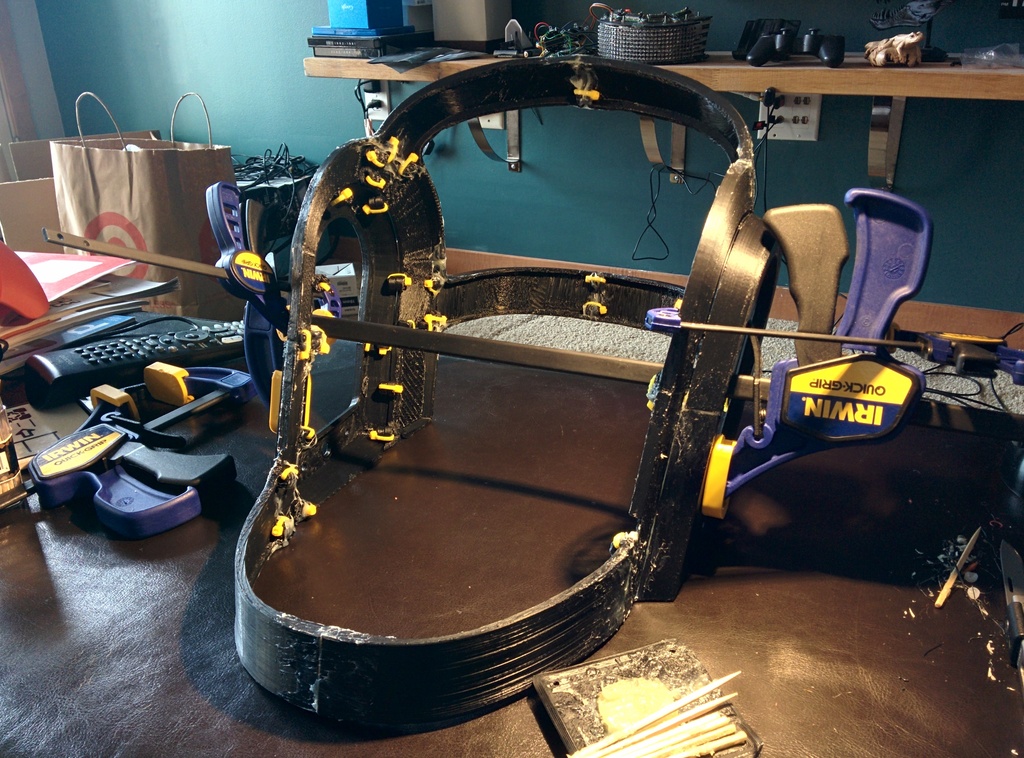
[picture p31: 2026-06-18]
daftpunkfiles/guy manual/images/September_08__2014_at_1208PM.jpg

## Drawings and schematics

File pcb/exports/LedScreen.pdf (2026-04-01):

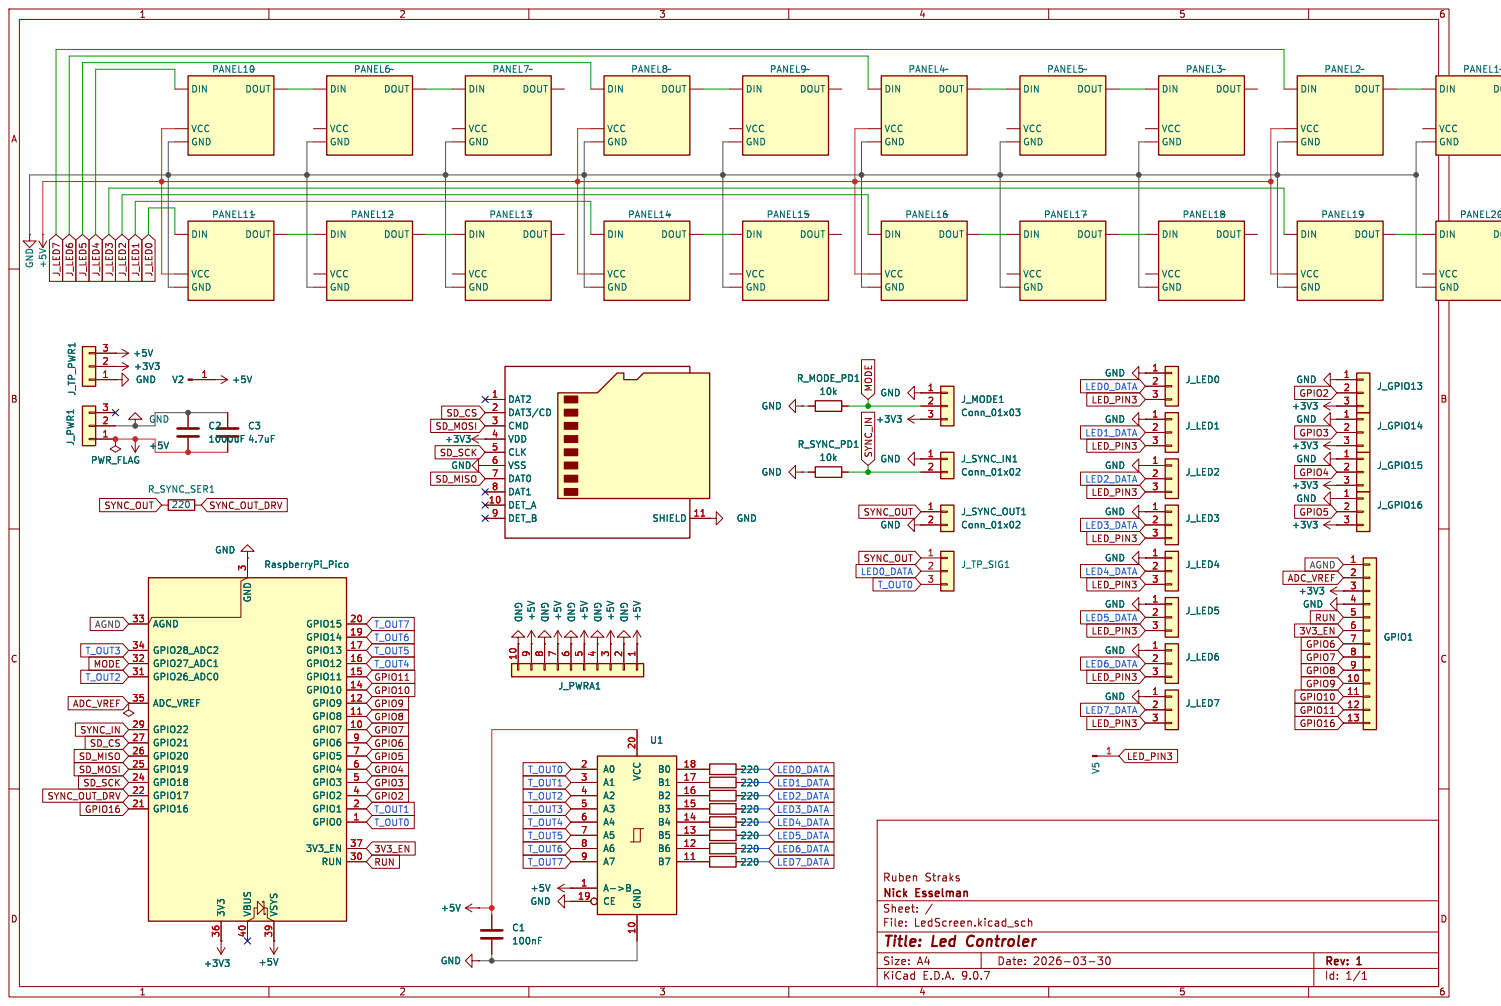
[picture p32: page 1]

3 3V3 36 GPIO16 21 GPIO17 22 GPIO18 24 GPIO19 25 GPIO20 26 GPIO21 27 GPIO22 29 ADC_VREF 35 GPIO26_ADC0 31 GPIO27_ADC1 32 GPIO28_ADC2 34 AGND 33 U1 A0 2 A1 3 A2 4 A3 5 A4 6 A5 7 A6 8 A7 9 A->B 1 CE 19 VCC 20 GND 10 B0 18 B1 17 B2 16 B3 15 B4 14 B5 13 B6 12 B7 11 +5V

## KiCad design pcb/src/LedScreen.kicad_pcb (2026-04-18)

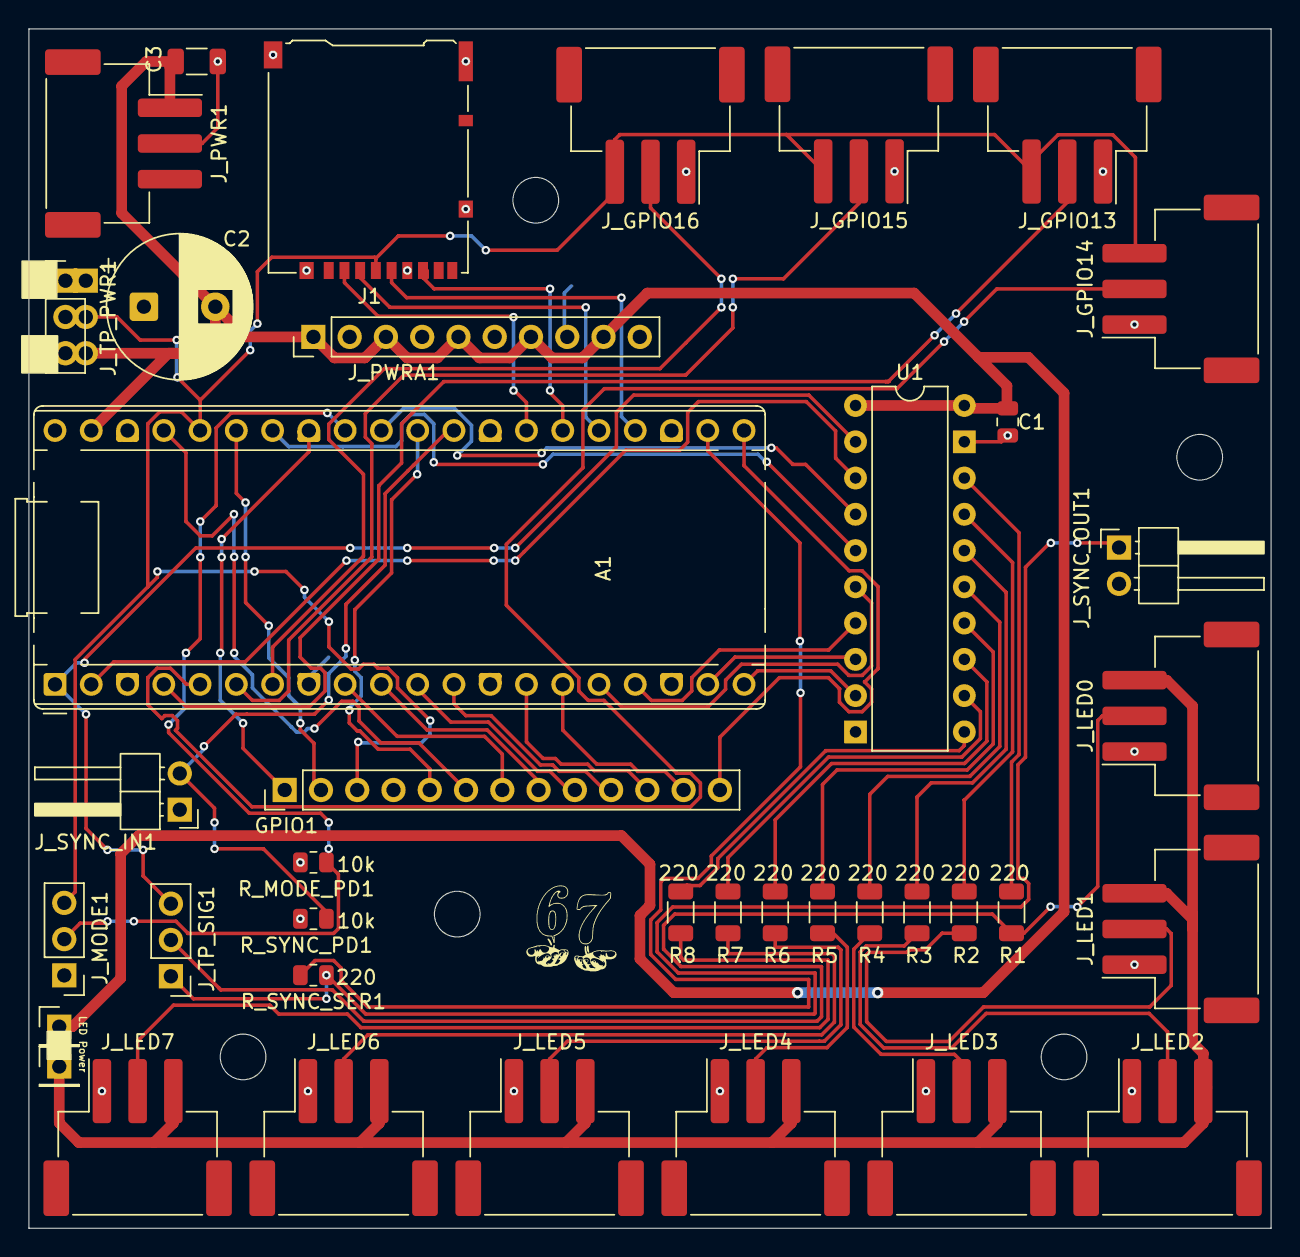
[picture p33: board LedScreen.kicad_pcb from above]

Board: 2 copper layers, 87.0 x 84.0 mm, 39 parts (0 on the bottom side), 51 nets.

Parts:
A1: RaspberryPi_Pico; RaspberryPi_Pico_Common_THT
C1: 100nF; C_0805_2012Metric
C2: 1000uF; CP_Radial_D10.0mm_P5.00mm
C3: 4.7uF; C_1206_3216Metric
GPIO1: Conn_01x13; PinHeader_1x13_P2.54mm_Vertical
J1: Micro_SD_Card_Det_Hirose_DM3AT; microSD_HC_Hirose_DM3AT-SF-PEJM5
J_GPIO13: SPARE_GPIO_13; JST_XH_S3B-XH-SM4-TB_1x03-1MP_P2.50mm_Horizontal
J_GPIO14: SPARE_GPIO_14; JST_XH_S3B-XH-SM4-TB_1x03-1MP_P2.50mm_Horizontal
J_GPIO15: SPARE_GPIO_15; JST_XH_S3B-XH-SM4-TB_1x03-1MP_P2.50mm_Horizontal
J_GPIO16: SPARE_GPIO_16; JST_XH_S3B-XH-SM4-TB_1x03-1MP_P2.50mm_Horizontal
J_LED0, J_LED1, J_LED2, J_LED3, J_LED4, J_LED5, J_LED6, J_LED7: Conn_01x03; JST_XH_S3B-XH-SM4-TB_1x03-1MP_P2.50mm_Horizontal
J_MODE1: Conn_01x03; PinHeader_1x03_P2.54mm_Vertical
J_PWR1: Conn_01x03; JST_XH_S3B-XH-SM4-TB_1x03-1MP_P2.50mm_Horizontal
J_PWRA1: Conn_01x10; PinHeader_1x10_P2.54mm_Vertical
J_SYNC_IN1: Conn_01x02; PinHeader_1x02_P2.54mm_Horizontal
J_SYNC_OUT1: Conn_01x02; PinHeader_1x02_P2.54mm_Horizontal
J_TP_PWR1: TP_PWR; PinHeader_1x03_P2.54mm_Vertical
J_TP_SIG1: TP_SIG; PinHeader_1x03_P2.54mm_Vertical
R1, R2, R3, R4, R5, R6, R7, R8: 220; R_1206_3216Metric
R_MODE_PD1: 10k; R_0805_2012Metric
R_SYNC_PD1: 10k; R_0805_2012Metric
R_SYNC_SER1: 220; R_0805_2012Metric
U1: 74HCT245; DIP-20_W7.62mm
V2, V5: Conn_01x01_Pin; PinHeader_1x01_P2.54mm_Vertical

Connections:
3V3_EN: A1.37 (3V3_EN), GPIO1.6
+3V3: A1.36 (3V3), GPIO1.3, J1.4 (VDD), J_GPIO13.3, J_GPIO14.3, J_GPIO15.3, J_GPIO16.3, J_MODE1.3, J_TP_PWR1.2
+5V: A1.39 (VSYS), C1.1, C2.2, C3.2, J_PWR1.1, J_PWRA1.1, J_PWRA1.3, J_PWRA1.5, J_PWRA1.7, J_PWRA1.9, J_TP_PWR1.3, U1.1 (A->B), U1.20 (VCC), V2.1
ADC_VREF: A1.35 (ADC_VREF), GPIO1.2
AGND: A1.33 (AGND), GPIO1.1
GND: A1.3 (GND), A1.8 (GND), A1.13 (GND), A1.18 (GND), A1.23 (GND), A1.28 (GND), A1.38 (GND), C1.2, C2.1, C3.1, GPIO1.4, J1.6 (VSS), J1.11 (SHIELD), J_GPIO13.1, J_GPIO14.1, J_GPIO15.1, J_GPIO16.1, J_LED0.1, J_LED1.1, J_LED2.1, J_LED3.1, J_LED4.1, J_LED5.1, J_LED6.1, J_LED7.1, J_MODE1.1, J_PWR1.2, J_PWRA1.2, J_PWRA1.4, J_PWRA1.6, J_PWRA1.8, J_PWRA1.10, J_SYNC_IN1.1, J_SYNC_OUT1.2, J_TP_PWR1.1, R_MODE_PD1.1, R_SYNC_PD1.1, U1.10 (GND), U1.19 (CE)
GPIO2: A1.4 (GPIO2), J_GPIO13.2
GPIO3: A1.5 (GPIO3), J_GPIO14.2
GPIO4: A1.6 (GPIO4), J_GPIO15.2
GPIO5: A1.7 (GPIO5), J_GPIO16.2
GPIO6: A1.9 (GPIO6), GPIO1.7
GPIO7: A1.10 (GPIO7), GPIO1.8
GPIO8: A1.11 (GPIO8), GPIO1.9
GPIO9: A1.12 (GPIO9), GPIO1.10
GPIO10: A1.14 (GPIO10), GPIO1.11
GPIO11: A1.15 (GPIO11), GPIO1.12
GPIO16: A1.21 (GPIO16), GPIO1.13
LED0_DATA: J_LED0.2, J_TP_SIG1.2, R1.2
LED1_DATA: J_LED1.2, R2.2
LED2_DATA: J_LED2.2, R3.2
LED3_DATA: J_LED3.2, R4.2
LED4_DATA: J_LED4.2, R5.2
LED5_DATA: J_LED5.2, R6.2
LED6_DATA: J_LED6.2, R7.2
LED7_DATA: J_LED7.2, R8.2
LED_PIN3: J_LED0.3, J_LED1.3, J_LED2.3, J_LED3.3, J_LED4.3, J_LED5.3, J_LED6.3, J_LED7.3, V5.1
MODE: A1.32 (GPIO27_ADC1), J_MODE1.2, R_MODE_PD1.2
unnamed: R1.1, U1.18 (B0)
unnamed: R2.1, U1.17 (B1)
unnamed: R3.1, U1.16 (B2)
unnamed: R4.1, U1.15 (B3)
unnamed: R5.1, U1.14 (B4)
unnamed: R6.1, U1.13 (B5)
unnamed: R7.1, U1.12 (B6)
unnamed: R8.1, U1.11 (B7)
RUN: A1.30 (RUN), GPIO1.5
SD_CS: A1.27 (GPIO21), J1.2 (DAT3/CD)
SD_MISO: A1.26 (GPIO20), J1.7 (DAT0)
SD_MOSI: A1.25 (GPIO19), J1.3 (CMD)
SD_SCK: A1.24 (GPIO18), J1.5 (CLK)
SYNC_IN: A1.29 (GPIO22), J_SYNC_IN1.2, R_SYNC_PD1.2
SYNC_OUT: J_SYNC_OUT1.1, J_TP_SIG1.1, R_SYNC_SER1.2
SYNC_OUT_DRV: A1.22 (GPIO17), R_SYNC_SER1.1
T_OUT0: A1.1 (GPIO0), J_TP_SIG1.3, U1.2 (A0)
T_OUT1: A1.2 (GPIO1), U1.3 (A1)
T_OUT2: A1.31 (GPIO26_ADC0), U1.4 (A2)
T_OUT3: A1.34 (GPIO28_ADC2), U1.5 (A3)
T_OUT4: A1.16 (GPIO12), U1.6 (A4)
T_OUT5: A1.17 (GPIO13), U1.7 (A5)
T_OUT6: A1.19 (GPIO14), U1.8 (A6)
T_OUT7: A1.20 (GPIO15), U1.9 (A7)

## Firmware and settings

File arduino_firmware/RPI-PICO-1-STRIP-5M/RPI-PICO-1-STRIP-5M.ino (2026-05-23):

#include <Adafruit_NeoPixel.h>
#include <Arduino.h>
#include "Config.h"

struct PhysicalPixel {
  uint8_t lane;
  uint16_t index;
};

constexpr uint16_t kLane0LedCount = static_cast<uint16_t>(kLivePanelsPerLane[0]) * kLiveLedsPerPanel;
constexpr uint16_t kLane1LedCount = static_cast<uint16_t>(kLivePanelsPerLane[1]) * kLiveLedsPerPanel;
constexpr uint16_t kLane2LedCount = static_cast<uint16_t>(kLivePanelsPerLane[2]) * kLiveLedsPerPanel;
constexpr uint16_t kLane3LedCount = static_cast<uint16_t>(kLivePanelsPerLane[3]) * kLiveLedsPerPanel;
constexpr uint16_t kLane4LedCount = static_cast<uint16_t>(kLivePanelsPerLane[4]) * kLiveLedsPerPanel;
constexpr uint16_t kLane5LedCount = static_cast<uint16_t>(kLivePanelsPerLane[5]) * kLiveLedsPerPanel;
constexpr uint16_t kLane6LedCount = static_cast<uint16_t>(kLivePanelsPerLane[6]) * kLiveLedsPerPanel;
constexpr uint16_t kLane7LedCount = static_cast<uint16_t>(kLivePanelsPerLane[7]) * kLiveLedsPerPanel;

Adafruit_NeoPixel strip0(kLane0LedCount, kLiveLanePins[0], NEO_GRB + NEO_KHZ800);
Adafruit_NeoPixel strip1(kLane1LedCount, kLiveLanePins[1], NEO_GRB + NEO_KHZ800);
Adafruit_NeoPixel strip2(kLane2LedCount, kLiveLanePins[2], NEO_GRB + NEO_KHZ800);
Adafruit_NeoPixel strip3(kLane3LedCount, kLiveLanePins[3], NEO_GRB + NEO_KHZ800);
Adafruit_NeoPixel strip4(kLane4LedCount, kLiveLanePins[4], NEO_GRB + NEO_KHZ800);
Adafruit_NeoPixel strip5(kLane5LedCount, kLiveLanePins[5], NEO_GRB + NEO_KHZ800);
Adafruit_NeoPixel strip6(kLane6LedCount, kLiveLanePins[6], NEO_GRB + NEO_KHZ800);
Adafruit_NeoPixel strip7(kLane7LedCount, kLiveLanePins[7], NEO_GRB + NEO_KHZ800);
Adafruit_NeoPixel* gStrips[kLiveLaneCount] = {
  &strip0,
  &strip1,
  &strip2,
  &strip3,
  &strip4,
  &strip5,
  &strip6,
  &strip7,
};

uint8_t  gFrameBuffer[kLiveFrameBytes];
size_t   gFrameIndex = 0;
uint32_t gLastSerialActivityMs = 0;

constexpr uint32_t kSerialActiveTimeoutMs = 500;
constexpr uint32_t kBootTestHoldMs = 600;


PhysicalPixel mapLogicalToPhysical(uint16_t logicalIndex) {
  uint16_t x = 0;
  uint16_t y = 0;

  if (kLiveInputColumnMajor) {
    x = logicalIndex / kLiveMatrixHeight;
    y = logicalIndex % kLiveMatrixHeight;
  } else {
    x = logicalIndex % kLiveMatrixWidth;
    y = logicalIndex / kLiveMatrixWidth;
  }

  if (kMatrixFlipX) x = kLiveMatrixWidth  - 1U - x;
  if (kMatrixFlipY) y = kLiveMatrixHeight - 1U - y;

  const uint16_t panelsWide = kLiveMatrixWidth / kLivePanelWidth;
  const uint16_t panelCol   = x / kLivePanelWidth;
  const uint16_t panelRow   = y / kLivePanelHeight;
  const uint16_t panelIndex = panelRow * panelsWide + panelCol;

  uint8_t panelInLane = static_cast<uint8_t>(panelIndex);
  uint8_t lane = 0;
  while (lane < kLiveLaneCount && panelInLane >= kLivePanelsPerLane[lane]) {
    panelInLane -= kLivePanelsPerLane[lane];
    lane++;
  }
  if (lane >= kLiveLaneCount) return {0, 0};

  uint16_t panelX = x % kLivePanelWidth;
  uint16_t panelY = y % kLivePanelHeight;

  if (kPanelRotationQuarterTurnsCCW == 1) {
    const uint16_t oldX = panelX;
    panelX = panelY;
    panelY = kLivePanelWidth - 1U - oldX;
  } else if (kPanelRotationQuarterTurnsCCW == 2) {
    panelX = kLivePanelWidth  - 1U - panelX;
    panelY = kLivePanelHeight - 1U - panelY;
  } else if (kPanelRotationQuarterTurnsCCW == 3) {
    const uint16_t oldY = panelY;
    panelY = panelX;
    panelX = kLivePanelHeight - 1U - oldY;
  }

  if (kMatrixSerpentine) {
    const bool oddRow     = (panelY & 1U) != 0;
    const bool reverseRow = kMatrixReverseOddRows ? oddRow : !oddRow;
    if (reverseRow) panelX = kLivePanelWidth - 1U - panelX;
  }

  const uint16_t pixelInPanel = panelY * kLivePanelWidth + panelX;
  const uint16_t laneIndex    = static_cast<uint16_t>(panelInLane) * kLiveLedsPerPanel + pixelInPanel;
  return {lane, laneIndex};
}


void renderFrameBuffer() {
  for (uint16_t logicalIndex = 0; logicalIndex < kLiveLedCount; logicalIndex++) {
    const size_t bufferIndex = static_cast<size_t>(logicalIndex) * 3U;
    for (uint8_t lane = 0; lane < kLiveLaneCount; lane++) {
      gStrips[lane]->setPixelColor(
        logicalIndex,
        gFrameBuffer[bufferIndex],
        gFrameBuffer[bufferIndex + 1],
        gFrameBuffer[bufferIndex + 2]
      );
    }
  }
  for (uint8_t lane = 0; lane < kLiveLaneCount; lane++) {
    gStrips[lane]->show();
  }
}


void serviceSerialStream() {
  while (Serial.available()) {
    const int incoming = Serial.read();
    if (incoming < 0) break;
    gLastSerialActivityMs = millis();
    if (gFrameIndex < kLiveFrameBytes)
      gFrameBuffer[gFrameIndex++] = static_cast<uint8_t>(incoming);
    if (gFrameIndex >= kLiveFrameBytes) {
      renderFrameBuffer();
      gFrameIndex = 0;
    }
  }
  if (gFrameIndex > 0 && (millis() - gLastSerialActivityMs) > kLiveFrameTimeoutMs)
    gFrameIndex = 0;
}

bool serialPlaybackActive() {
  return (millis() - gLastSerialActivityMs) <= kSerialActiveTimeoutMs;
}


static uint16_t gScannerPixel     = 0;
static uint16_t gScannerPrevPixel = 0xFFFFU;
static uint32_t gNextScanMs       = 0;
static bool     gScannerActive    = false;

constexpr uint32_t kScanStepMs = 10;

static void showSolidColor(uint8_t red, uint8_t green, uint8_t blue) {
  for (uint8_t lane = 0; lane < kLiveLaneCount; lane++) {
    for (uint16_t pixel = 0; pixel < kLiveLedCount; pixel++) {
      gStrips[lane]->setPixelColor(pixel, red, green, blue);
    }
    gStrips[lane]->show();
  }
}

static void runBootTest() {
  showSolidColor(40, 0, 0);
  delay(kBootTestHoldMs);
  showSolidColor(0, 40, 0);
  delay(kBootTestHoldMs);
  showSolidColor(0, 0, 40);
  delay(kBootTestHoldMs);
  showSolidColor(0, 0, 0);
}

static void resetScannerTest() {
  for (uint8_t lane = 0; lane < kLiveLaneCount; lane++) {
    gStrips[lane]->clear();
    gStrips[lane]->show();
  }
  gScannerPixel     = 0;
  gScannerPrevPixel = 0xFFFFU;
  gNextScanMs       = millis();
  gScannerActive    = true;
}

static void updateScannerTest() {
  const uint32_t now = millis();
  if (static_cast<int32_t>(now - gNextScanMs) < 0) return;

  if (gScannerPrevPixel < kLiveLedCount) {
    for (uint8_t lane = 0; lane < kLiveLaneCount; lane++) {
      gStrips[lane]->setPixelColor(gScannerPrevPixel, 0, 0, 0);
    }
  }

  for (uint8_t lane = 0; lane < kLiveLaneCount; lane++) {
    gStrips[lane]->setPixelColor(gScannerPixel, 0, 40, 0);
    gStrips[lane]->show();
  }

  gScannerPrevPixel = gScannerPixel;
  gScannerPixel     = (gScannerPixel + 1) % kLiveLedCount;
  gNextScanMs       = now + kScanStepMs;
}


void setup() {
  Serial.begin(kLiveSerialBaud);
  delay(1000);

  for (uint8_t lane = 0; lane < kLiveLaneCount; lane++) {
    gStrips[lane]->begin();
    gStrips[lane]->clear();
    gStrips[lane]->setBrightness((kGeneralMaxBrightnessPercent * 255U) / 100U);
    gStrips[lane]->show();
  }

  runBootTest();
}

void loop() {
  serviceSerialStream();
  if (serialPlaybackActive()) {
    gScannerActive = false;
    return;
  }
  if (!gScannerActive) resetScannerTest();
  updateScannerTest();
}

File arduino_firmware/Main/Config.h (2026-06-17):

#pragma once
#include <Arduino.h>

// kGeneralMaxBrightnessPercent caps output (100 = PSU-limited only, lower to hard-cap brightness).
constexpr uint8_t  kGeneralMaxBrightnessPercent = 25;
constexpr uint32_t kPsuCurrentMa                = 30000;
constexpr uint32_t kLedMaPerChannel             = 20;

// Lane order follows the PCB routing, not the visual left-to-right panel order.
constexpr uint8_t kLiveLaneCount = 8;
constexpr uint8_t kLiveLanePins[kLiveLaneCount]      = {12, 13, 14, 15,  0,  1, 26, 28};
constexpr uint8_t kLivePanelsPerLane[kLiveLaneCount] = { 2,  3,  2,  3,  2,  3,  2,  3};

constexpr uint16_t kLivePanelWidth   = 16;
constexpr uint16_t kLivePanelHeight  = 16;
constexpr uint16_t kLiveLedsPerPanel = 256;
constexpr uint8_t  kLivePanelCount   = 20;

constexpr uint16_t kLiveMatrixWidth  = 160;
constexpr uint16_t kLiveMatrixHeight = 32;
constexpr uint16_t kLiveLedCount     = 5120;
constexpr size_t   kLiveFrameBytes   = 15360;

constexpr bool    kLiveInputColumnMajor         = false;
constexpr uint8_t kPanelRotationQuarterTurnsCCW = 3;
constexpr bool    kMatrixSerpentine             = true;
constexpr bool    kMatrixReverseOddRows         = true;

constexpr bool    kMatrixFlipX                  = false;
constexpr bool    kMatrixFlipY                  = true;

// ── Whole-row corrections ─────────────────────────────────────────────────
// Rotates the entire row 180°: pixel (0,0) becomes pixel (159,15) and vice versa.
// Affects both panel order and content within every panel simultaneously.
constexpr bool    kTopRowRot180                 = false;
constexpr bool    kBotRowRot180                 = true;

// Reverses only the left-to-right ORDER of panels, content within each panel unchanged.
// Use when the entire row is cabled right-to-left instead of left-to-right.
constexpr bool    kTopRowReverseX               = false;
constexpr bool    kBotRowReverseX               = false;

// ── Per-panel content corrections ─────────────────────────────────────────
// Each flag applies independently to every panel in that row.
// Use when panels are physically mounted in a non-standard orientation.
constexpr bool    kTopPanelRot180               = false;  // rotate 180° (= flipX + flipY)
constexpr bool    kBotPanelRot180               = false;

constexpr bool    kTopPanelFlipX                = false;  // mirror each panel left↔right
constexpr bool    kBotPanelFlipX                = false;

constexpr bool    kTopPanelFlipY                = false;  // mirror each panel top↔bottom
constexpr bool    kBotPanelFlipY                = false;

constexpr uint8_t kSdCs   = 21;
constexpr uint8_t kSdMosi = 19;
constexpr uint8_t kSdMiso = 20;
constexpr uint8_t kSdSck  = 18;

constexpr uint32_t kLiveSerialBaud = 115200UL;

constexpr uint32_t kSdRetryIntervalMs = 3000;
constexpr uint32_t kSdReadSpeedHz     = 25000000UL;

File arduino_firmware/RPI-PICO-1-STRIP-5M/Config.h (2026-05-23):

#pragma once

#include <Arduino.h>

constexpr uint8_t kLedOutputCount = 8;
constexpr uint8_t kLedGpioByOutput[kLedOutputCount] = {
  0,   // GPOIO 0 output 0: T_OUT0 / LED0_DATA / J_LED0
  1,   // GPOIO 1 output 1: T_OUT1 / LED1_DATA / J_LED1
  26,  // GPOIO 26 output 2: T_OUT2 / LED2_DATA / J_LED2
  28,  // GPOIO 28 output 3: T_OUT3 / LED3_DATA / J_LED3
  12,  // GPOIO 12 output 4: T_OUT4 / LED4_DATA / J_LED4
  13,  // GPOIO 13 output 5: T_OUT5 / LED5_DATA / J_LED5
  14,  // GPOIO 14 output 6: T_OUT6 / LED6_DATA / J_LED6
  15   // GPOIO 15 output 7: T_OUT7 / LED7_DATA / J_LED7
};

// Mirrored single-strip variant using all LED connectors/outputs.
constexpr uint8_t kLiveLaneCount = 8;
constexpr uint8_t kLiveLaneOutputs[kLiveLaneCount] = {0, 1, 2, 3, 4, 5, 6, 7};
constexpr uint8_t kLiveLanePins[kLiveLaneCount] = {
  kLedGpioByOutput[kLiveLaneOutputs[0]],
  kLedGpioByOutput[kLiveLaneOutputs[1]],
  kLedGpioByOutput[kLiveLaneOutputs[2]],
  kLedGpioByOutput[kLiveLaneOutputs[3]],
  kLedGpioByOutput[kLiveLaneOutputs[4]],
  kLedGpioByOutput[kLiveLaneOutputs[5]],
  kLedGpioByOutput[kLiveLaneOutputs[6]],
  kLedGpioByOutput[kLiveLaneOutputs[7]],
};

// Assumes a 5 m strip at 60 LEDs/m. Adjust if your strip density differs.
constexpr uint16_t kSingleStripLedCount = 300;
constexpr uint8_t kLivePanelsPerLane[kLiveLaneCount] = {1, 1, 1, 1, 1, 1, 1, 1};

constexpr uint16_t kLivePanelWidth = kSingleStripLedCount;
constexpr uint16_t kLivePanelHeight = 1;
constexpr uint16_t kLiveLedsPerPanel = kLivePanelWidth * kLivePanelHeight;  // 300
constexpr uint8_t kLivePanelCount = 1;

constexpr uint16_t kLiveMatrixWidth = kLivePanelWidth;                       // 300
constexpr uint16_t kLiveMatrixHeight = kLivePanelHeight;                     // 1
constexpr uint16_t kLiveLedCount = kLiveMatrixWidth * kLiveMatrixHeight;     // 300
constexpr size_t kLiveFrameBytes = static_cast<size_t>(kLiveLedCount) * 3U;  // 900

constexpr uint32_t kLiveSerialBaud = 500000UL;
constexpr uint32_t kLiveFrameTimeoutMs = 50UL;





// Brightness/power safety.
constexpr uint8_t kGeneralMaxBrightnessPercent = 20;
constexpr uint32_t kMaxCurrentMa = 2000UL;
constexpr uint32_t kLedMaPerChannel = 20UL;



constexpr bool kLiveInputColumnMajor = false;
constexpr uint8_t kPanelRotationQuarterTurnsCCW = 0;
constexpr bool kMatrixSerpentine = false;
constexpr bool kMatrixReverseOddRows = false;
constexpr bool kMatrixFlipX = false;
constexpr bool kMatrixFlipY = false;

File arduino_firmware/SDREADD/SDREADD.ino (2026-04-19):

#include <Arduino.h>
#include <SPI.h>
#include "hardware/gpio.h"

namespace {

constexpr const char* kVersion  = "v1.1.0";

constexpr uint8_t  kCs         = 21;
constexpr uint8_t  kMosi       = 19;
constexpr uint8_t  kMiso       = 20;
constexpr uint8_t  kSck        = 18;
constexpr uint32_t kInitHz     = 400000UL;
constexpr uint32_t kDataHz     = 8000000UL;
constexpr uint16_t kSectorSize = 512;

SPIClassRP2040& gSpi  = SPI;
bool            gSdhc = false;

// ── SPI primitives ─────────────────────────────────────────────────────────────

inline uint8_t xfer(uint8_t b = 0xFF) { return gSpi.transfer(b); }
inline void    csLow()  { digitalWrite(kCs, LOW); }
inline void    csHigh() { digitalWrite(kCs, HIGH); xfer(); }

uint8_t waitR1() {
  for (uint8_t i = 0; i < 8; ++i) {
    uint8_t b = xfer();
    if (b != 0xFF) return b;
  }
  return 0xFF;
}

// ── SD commands ────────────────────────────────────────────────────────────────
uint8_t sendCmd(uint8_t cmd, uint32_t arg, uint8_t crc) {
  xfer();  // NCC: ≥8 idle clocks between frames
  xfer(0x40 | cmd);
  xfer(arg >> 24); xfer(arg >> 16); xfer(arg >> 8); xfer(arg);
  xfer(crc);
  return waitR1();
}

uint8_t sendACmd(uint8_t acmd, uint32_t arg) {
  sendCmd(55, 0, 0x65);    // CRC7 for CMD55 arg=0 + stop bit
  xfer(); xfer(); xfer();  // 24 idle clocks gap before ACMD frame
  xfer(0x40 | acmd);
  xfer(arg >> 24); xfer(arg >> 16); xfer(arg >> 8); xfer(arg);
  xfer(0x01);              // stop bit; CRC disabled after CMD0
  return waitR1();
}

// ── Initialisation ─────────────────────────────────────────────────────────────
bool sdInit() {
  gSpi.end();
  gSpi.setRX(kMiso); gSpi.setTX(kMosi); gSpi.setSCK(kSck);
  gSpi.begin();
  gpio_pull_up(kMiso);
  pinMode(kCs, OUTPUT);

  gSpi.beginTransaction(SPISettings(kInitHz, MSBFIRST, SPI_MODE0));
  csHigh(); delay(2);
  for (uint8_t i = 0; i < 10; ++i) xfer();
  csLow();

  const auto abort = [&]() -> bool { csHigh(); gSpi.endTransaction(); return false; };

  if (sendCmd(0, 0, 0x95) != 0x01) return abort();

  if (sendCmd(8, 0x1AA, 0x87) != 0x01) return abort();
  uint8_t r7[4]; for (auto& b : r7) b = xfer();
  if (r7[2] != 0x01 || r7[3] != 0xAA) return abort();

  uint8_t r = 0x01;
  for (uint32_t t = millis(); r == 0x01 && millis() - t < 1000; ) {
    csHigh(); csLow();
    r = sendACmd(41, 0x40000000);
  }
  if (r != 0x00) return abort();

  if (sendCmd(58, 0, 0x01) != 0x00) return abort();
  uint8_t ocr[4]; for (auto& b : ocr) b = xfer();
  gSdhc = (ocr[0] & 0x40) != 0;

  if (!gSdhc) {
    csHigh(); csLow();
    if (sendCmd(16, kSectorSize, 0x01) != 0x00) return abort();
  }

  csHigh();
  gSpi.endTransaction();
  return true;
}

// ── Sector read ────────────────────────────────────────────────────────────────
bool sdRead(uint32_t lba, uint8_t* buf) {
  const uint32_t addr = gSdhc ? lba : lba * kSectorSize;

  gSpi.beginTransaction(SPISettings(kDataHz, MSBFIRST, SPI_MODE0));
  csLow();

  if (sendCmd(17, addr, 0x01) != 0x00) {
    csHigh(); gSpi.endTransaction(); return false;
  }

  bool ok = false;
  for (uint32_t i = 0; i < 50000 && !ok; ++i) ok = xfer() == 0xFE;
  if (!ok) { csHigh(); gSpi.endTransaction(); return false; }

  for (uint16_t i = 0; i < kSectorSize; ++i) buf[i] = xfer();
  xfer(); xfer();

  csHigh();
  gSpi.endTransaction();
  return true;
}

// ── Utilities ──────────────────────────────────────────────────────────────────
void printHex(const uint8_t* d, size_t n) {
  for (size_t i = 0; i < n; ++i) {
    if (d[i] < 0x10) Serial.print('0');
    Serial.print(d[i], HEX);
    if (i + 1 < n) Serial.print(' ');
  }
  Serial.println();
}

}

void setup() {
  Serial.begin(115200);
  while (!Serial && millis() < 3000) {}
  Serial.print(F("SDREADD  fw=")); Serial.println(kVersion);

  if (!sdInit()) { Serial.println(F("Init: FAIL")); return; }
  Serial.print(F("Init: PASS  ")); Serial.println(gSdhc ? F("SDHC/SDXC") : F("SDSC"));

  uint8_t buf[kSectorSize];
  if (!sdRead(0, buf)) { Serial.println(F("Sector 0: FAIL")); return; }
  Serial.print(F("Sector 0 [0..31]: ")); printHex(buf, 32);
}

void loop() { delay(1000); }

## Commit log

2026-02-27 added caps to 5v + gnd
    [LedScreen.kicad_sch]
2026-03-01 DONE WIRINg
    [LedScreen.kicad_pcb, LedScreen.kicad_sch]
2026-03-02 removed all tracks
    [LedScreen.kicad_pcb]
2026-03-03 finsighed new v2 routing
    [LedScreen.kicad_pcb, LedScreen.kicad_sch]
2026-03-03 Reorganize KiCad project layout
    [LedScreen.kicad_pcb, LedScreen.kicad_sch]
2026-03-03 Update Teensy library submodule refs
2026-03-03 added Bom+Journal
    [LedScreen.kicad_pcb, LedScreen.kicad_sch]
2026-03-04 FIRMWARE DONEE!
    [LedScreen.kicad_pcb]
2026-03-07 Updare README
    [LedScreen.kicad_pcb]
2026-03-09 FINAL BLOWW! added gerbers added new images, uploaded carts
    [LedScreen-B_Cu.gbl, LedScreen-B_Mask.gbs, LedScreen-B_Silkscreen.gbo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]
2026-03-17 made .blend standoff files
    [StandOff.blend]
2026-03-18 updated models for more Stiffness
    [StandOff.3mf, StandOff.blend, StandOff.stl]
2026-03-22 Add image of PCB to README
2026-04-01 updated power injection wireing
    [LedScreen.kicad_sch]
2026-04-14 AGAGAHAGAHAGHAGAH op schoool
    [StandOff.3mf, StandOff.blend, StandOff.stl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]
2026-04-18 Add Main firmware, SDREADD, fseq converter; clean up AI/build artifacts
    - arduino_firmware/Main/: new combined firmware
    - Sd.cpp/h: bare-metal SPI SD driver + FAT32 + LSA streaming
    - Leds.cpp/h: 8-lane NeoPixel, pixel mapping, idle blink, current limit
    - UsbStream.cpp/h: xLights USB serial streaming with frame sync
    - Main.ino: setup + loop only
    - Config.h: 20-panel (160×32) layout, safety limits at top
    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
    [LedScreen.kicad_pcb, LedScreen.kicad_sch]
2026-04-19 Switch to Adafruit NeoPXL8 for true parallel 8-lane output
    Replaces 8 separate NeoPixel show() calls (sequential, ~154ms, ~6.5fps max)
    with a single NeoPXL8 show() via RP2040 PIO+DMA — all lanes fire simultaneously
    (~23ms for longest lane → ~43fps max). Fixes panel sync drift.
    Also: pin order corrected (lanes 0-3 → GPIOs 12-15 physical top row, lanes 4-7
    → GPIOs 0,1,26,28 physical bottom), orphaned serial stream stubs removed from
    Leds.cpp, xlights project and animation.lsa updated.
    Requires "Adafruit NeoPXL8" library installed via Arduino Library Manager.
    [Config.h, Leds.cpp]
2026-04-19 switched to a adafruit library and got 43fps working
2026-04-19 Clean up the repository structure so project assets are easier to find
    The project had accumulated PCB exports, mechanical files, screenshots,
    examples, and helper scripts at the repo root. Group related artifacts
    under docs/, pcb/, mechanical/, examples/, and scripts/ so the root stays
    readable and common assets are easier to locate.
    Constraint: Preserve existing project contents while reorganizing tracked assets
    Constraint: Keep the example UF2 tracked after moving it under examples/
    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
    [LedScreen-B_Cu.gbl, LedScreen-B_Mask.gbs, LedScreen-B_Silkscreen.gbo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]
2026-04-19 Add build photos to the README so the hardware state is easier to see
    The repository already had renders and fabrication screenshots, but it was
    missing clear photos of the assembled controller and panel test setup. Add
    both images under docs/images/ and link them from the README.
    Constraint: Keep the photos inside the existing docs image structure
    Confidence: high
    Scope-risk: narrow
    Directive: Place future README photos under docs/images and reference them by relative path
    Tested: Verified README references and file paths locally
    Not-tested: Remote markdown rendering on GitHub
2026-04-29 lamp fully working all panel corrections +gif and mp4 script start implementing
    [Leds.cpp, Main.ino, Sd.cpp]
2026-05-23 added BOMs
    [BOM.csv, BOM.xlsx]
2026-06-18 added the daftpunk helmets models
    [BackBar-v1.5.stl, BackWireHarness-V1.5.stl, Chin-v1.5.stl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]
